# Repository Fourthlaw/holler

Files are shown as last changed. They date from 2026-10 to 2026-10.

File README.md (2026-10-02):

# Holler

**Whole-home audio and intercom.** Synchronized music in every room and a push-to-talk intercom, built yourself. A Raspberry Pi runs the house. Small ESP32-S3 speakers in each room play the music and carry the pages. Paired iPhone and Android apps page the house from anywhere. The music comes from Plex or from a plain network share.

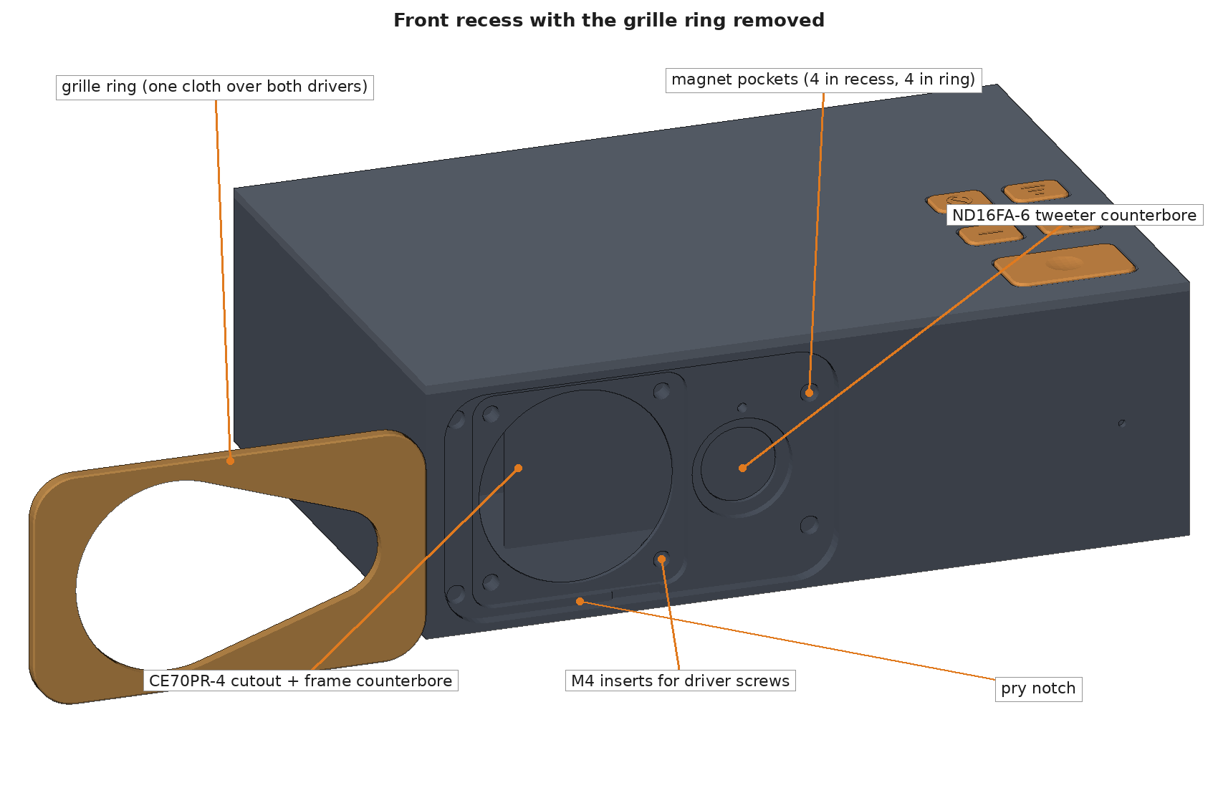
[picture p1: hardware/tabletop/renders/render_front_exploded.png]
Tabletop endpoint with the magnetic grille removed


> **Status: design stage.** The system design and first printable designs for two speakers (tabletop and in-wall) are here. No firmware, controller software, or phone app has been written yet, and nothing has been printed or tested. Expect things to change.

The name comes from what it replaces, hollering across the house, and from "hoot-n-holler," the old term for an always-open intercom line.

## What it does

- **Music in every room, in sync.** One stream plays through the whole house with no echo between rooms.
- **Your library, two ways.** Use Plex and pick music in Plexamp (needs a Plex Pass), or point it at a network share and pick music from a web page or any MPD app, with no account at all.
- **Background mode.** Any room can switch to a soft "music from the other room" sound for dinner or conversation, while the rest of the house plays normally. One button on the speaker turns it on or off, and the server can schedule it.
- **Push-to-talk intercom.** Hold TALK in any room to page every other room. Music ducks while someone is talking, then comes back.
- **Priority page.** Double-press TALK to get through to rooms that are turned down.
- **Phone apps.** A paired iPhone or Android phone can page the house and hear house pages from anywhere, with no VPN.
- **Two ways to reach home.** By default the phone and the house meet through a small server you host, and no port is opened at home. A simpler direct option forwards two ports instead, with no server to run, at the cost of exposing a service at home.
- **Works through a power blip.** The tabletop speaker has a battery that keeps it online for hours.

## Privacy comes first

A microphone in every room has to be provably off.

- A room's mic has power only while someone in that room is holding TALK **and** that room's mic mute is off.
- Both conditions are wired in hardware. The firmware can see the state but has no wire that can change it, so a software bug or a compromised device cannot turn a mic on.
- A soft red glow behind the speaker cloth shows mic mute. It is driven by the same hardware latch, so it cannot be faked.
- No bright lights. Every indicator is indirect and dim enough for a bedroom at night.
- Nothing remote can listen to a room. The phone app can talk to the house and hear a page that someone in the house chose to send. That is all.
- Whatever sits between a phone and the house, a hosted server or the open internet, only ever carries encrypted audio it cannot decrypt.

## How it fits together

```mermaid
flowchart LR
    Library[Music library<br/>Plex server or network share] --> Player
    subgraph Pi[Raspberry Pi 5 controller]
        Player[Plexamp or MPD] --> Snap[Snapserver<br/>synced music]
        Intercom[Intercom server]
        Gateway[Remote gateway]
        Web[Web app and MQTT]
    end
    Snap --> Rooms
    Intercom <--> Rooms
    subgraph Rooms[Room endpoints, ESP32-S3]
        Table[Tabletop speaker]
        Wall[In-wall speaker, optional]
    end
    Gateway <-->|outbound only| Cloud[Rendezvous server<br/>cloud, untrusted]
    Phone[iPhone and Android<br/>PTT apps] <--> Cloud
    Phone -.->|direct mode, optional| Gateway
```

| Part | What it is |
|---|---|
| Controller | Raspberry Pi 5 running Snapcast for music, the intercom server, MQTT, and a local web app |
| Music library | Plex mode: Plex Media Server with a headless Plexamp player on the Pi, controlled from Plexamp. Share mode: a network share played by MPD on the Pi, controlled from a web page or any MPD app. Either one feeds Snapcast |
| Tabletop endpoint | ESP32-S3, 2.5 in. woofer and dome tweeter in a folded transmission line, USB-C power, battery backup. This is the reference build |
| In-wall endpoint (optional) | ESP32-S3, 2 in. speaker, and mic behind a printed plate in a double-gang box. One Ethernet cable brings power (PoE) and data; there is no other power option. Same audio electronics and firmware. Parts are modeled, not yet printed |
| Phone apps | Push-to-talk apps for iPhone (WebRTC and Apple's PushToTalk framework) and Android (WebRTC and a foreground service) |
| Rendezvous server (default) | A small hosted server that helps the phone and the house find each other and punch through to each other. It relays encrypted audio and never holds the keys |
| Direct mode (optional) | No hosted server. The router forwards two ports to the Pi's remote gateway. Simpler and free, but it exposes a service at home to the internet |

The full design, including the mic privacy circuit, the audio processing chain, and the remote intercom trust model, is in **[docs/design.md](docs/design.md)**.

## The tabletop speaker

| | |
|---|---|
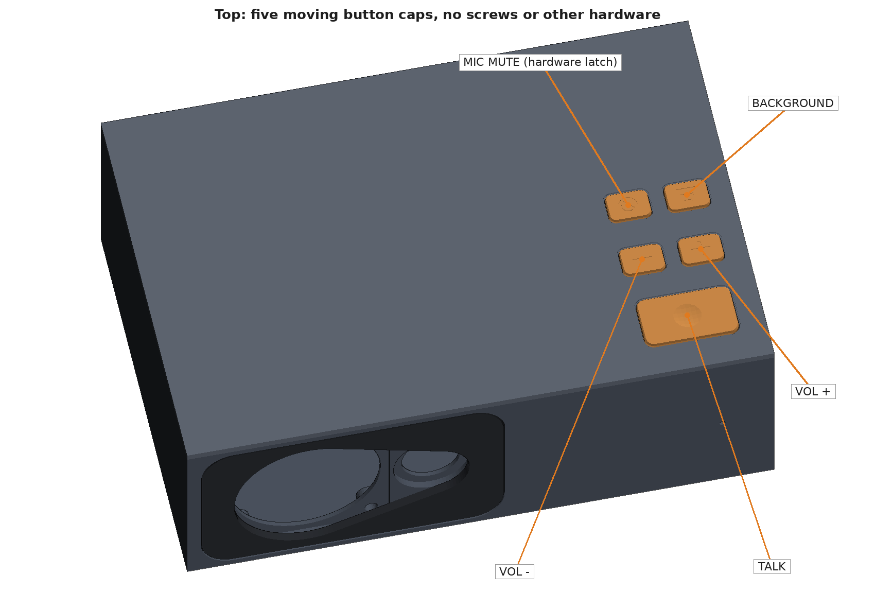
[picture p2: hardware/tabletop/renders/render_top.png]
Top view with the five buttons
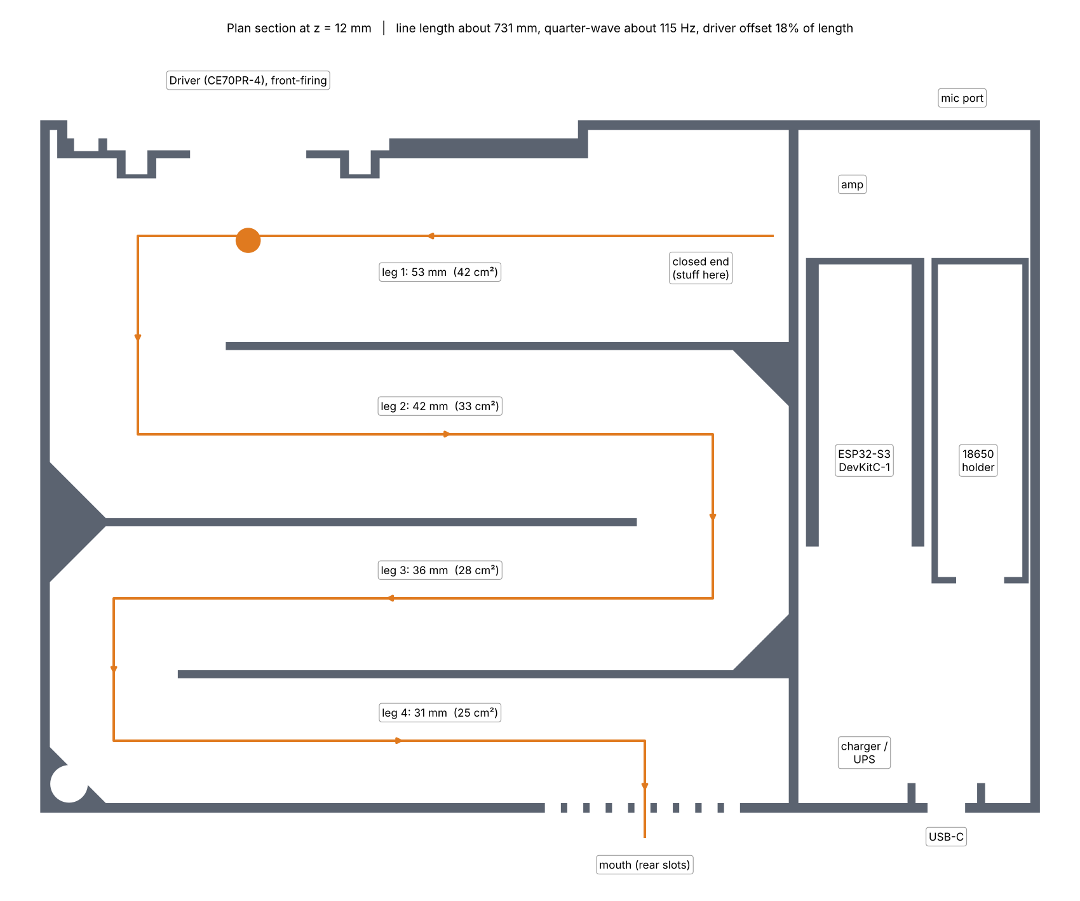
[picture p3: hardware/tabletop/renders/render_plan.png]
Transmission line layout
|  |  |

- 250 x 173 x 84 mm. Prints on a Bambu Lab A1 (256 mm bed) in PETG with no supports.
- Dayton Audio CE70PR-4 2.5 in. woofer and ND16FA-6 tweeter, one amp channel each, with the crossover and EQ done in software.
- A folded transmission line about 730 mm long behind the woofer, tuned to about 115 Hz.
- Five real buttons on top: TALK, volume down, volume up, mic mute, and background mode. No screws on top; they come in from the bottom.
- A cloth grille on a printed ring that snaps on with magnets.
- The status glow sits behind the cloth. Nothing lit points at the room.
- More detail, the hardware list, and assembly steps are in [`hardware/tabletop/`](hardware/tabletop/).

### Print it or change it

| File | Print orientation |
|---|---|
| `hardware/tabletop/base.stl` | Floor on the bed |
| `hardware/tabletop/lid.stl` | Top face on the bed |
| `hardware/tabletop/button_caps.stl` | Cap tops on the bed |
| `hardware/tabletop/grille_ring.stl` | Front face on the bed |

Every dimension is a named parameter at the top of `tabletop_endpoint.py`. Change one and regenerate:

```
cd hardware/tabletop
pip install manifold3d trimesh numpy pillow matplotlib
python3 tabletop_endpoint.py     # writes the STLs
python3 render_views.py          # writes preview images to renders/
python3 render_plan.py           # writes the line layout to renders/
```

Dimensions marked `VERIFY` in the script are estimates. Check them against the parts in hand before printing.

## The in-wall option

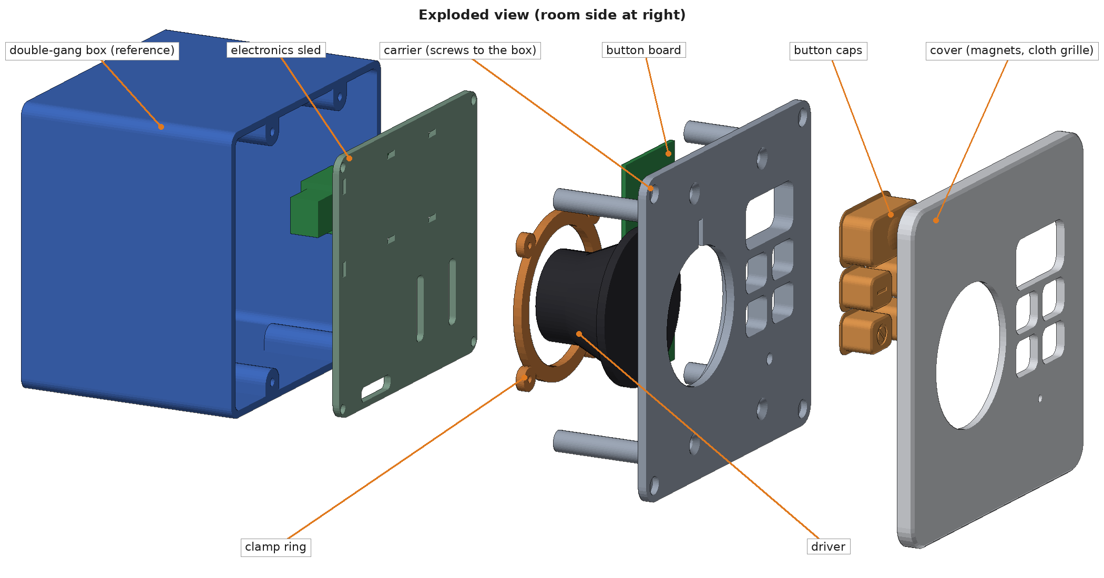
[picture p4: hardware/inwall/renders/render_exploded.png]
In-wall endpoint, exploded


For new construction or a remodel, the same electronics fit a standard double-gang electrical box.

- One Ethernet cable from a PoE switch brings power and data. That is the only power option, so no line voltage comes near the box.
- Everything mounts on one printed carrier that screws to the box's standard device holes. A cover snaps on with magnets, so no screws show.
- One 2 in. driver, the same five buttons, and the same hardware mic gating.
- Parts, hardware list, and assembly steps are in [`hardware/inwall/`](hardware/inwall/).

## What is in this repo

| Folder | What it holds | Status |
|---|---|---|
| [`docs/`](docs/) | System design | Current |
| [`hardware/tabletop/`](hardware/tabletop/) | Tabletop enclosure: generator, STLs, renders | First design, not yet printed |
| [`hardware/inwall/`](hardware/inwall/) | In-wall endpoint (optional): generator, STLs, renders | First design, not yet printed |
| [`firmware/endpoint/`](firmware/endpoint/) | ESP32-S3 firmware for both endpoint types | Not started |
| [`controller/`](controller/) | Pi 5 services | Not started |
| [`remote/`](remote/) | Remote intercom: Pi gateway, rendezvous server, iPhone and Android apps | Not started |

## Roadmap

- [x] System design
- [x] Tabletop enclosure, first design
- [ ] Print and fit-check the tabletop enclosure
- [ ] Mic privacy board (latch, load switches, buffer)
- [ ] Endpoint firmware: music playback, then intercom, then audio tuning and background mode
- [ ] Controller: Snapcast, Plexamp or MPD, intercom server, web app
- [x] In-wall endpoint parts, first design (optional)
- [ ] Remote intercom on the local network (web page)
- [ ] Rendezvous server and iPhone app
- [ ] Android app
- [ ] Direct mode (port forward) as an option

## Feedback

Ideas, corrections, and questions are welcome. Open an [issue](../../issues). Review of the mic privacy circuit and the remote intercom trust model is especially useful.

## License

No license has been chosen yet. Until one is added, the contents are published for reading and all rights are reserved.

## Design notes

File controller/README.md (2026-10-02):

# Holler controller (Raspberry Pi 5)

Not started. Services planned (see docs/design.md, section 2):

- Music source, one of two modes:
  - Plex mode: Plex Media Server for the library (here or on another machine) and Plexamp headless as the house player, feeding Snapserver through an ALSA loopback
  - Share mode: MPD playing from a network share into a Snapserver pipe, with a music page in the web app
- Snapserver for synchronized music
- Intercom server: PTT arbitration, Opus relay, priority pages
- Mosquitto MQTT broker with per-device credentials
- Web app (Flask or FastAPI): music, volumes, schedules, phone pairing
- Scheduler for alarms and announcements

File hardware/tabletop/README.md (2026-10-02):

# Holler tabletop endpoint

The reference build: a desktop speaker with USB-C power and a battery that carries it through outages. This is a first design. It has been modeled and checked for fit, but not yet printed.

See docs/design.md, section 3.4, for the full design.

Front, with the grille ring removed

| | |
|---|---|
| Top | Transmission line layout |

## What it is

- 250 x 173 x 84 mm, printed in PETG on a Bambu Lab A1 with no supports
- Dayton Audio CE70PR-4 2.5 in. woofer and ND16FA-6 tweeter, front-mounted in a recess, each on its own MAX98357A amp, with the crossover in software
- A folded transmission line about 730 mm long behind the woofer, tuned to about 115 Hz
- ESP32-S3-DevKitC-1 on Wi-Fi, INMP441 mic, USB-C power, and an 18650 cell for backup
- Five moving button caps on top: TALK, VOL -, VOL +, MIC MUTE, BACKGROUND
- A cloth grille on a printed ring held by magnets
- Lid screws come up through the bottom, so nothing shows on top but the buttons
- The status glow is indirect: an LED under the grille ring shines sideways behind the cloth

## Parts

| File | What it is | Print orientation |
|---|---|---|
| `base.stl` | Case, transmission line, electronics bay | Floor on the bed |
| `lid.stl` | Top, button guides, and the pillars the bottom screws thread into | Top face on the bed |
| `button_caps.stl` | All five caps on one plate | Cap tops on the bed |
| `grille_ring.stl` | Magnetic frame for the speaker cloth | Front face on the bed |

The base uses roughly 450 to 500 g of PETG and nearly fills the A1 bed. Print one cap and a small test piece of the lid first to check the cap fit.

## Hardware

| Item | Qty |
|---|---|
| Dayton Audio CE70PR-4 woofer and ND16FA-6 tweeter | 1 each |
| MAX98357A I2S amp breakout | 2 |
| 10 to 22 uF film capacitor (in series with the tweeter) | 1 |
| ESP32-S3-DevKitC-1, INMP441 mic module | 1 each |
| 18650 cell and holder, power-path charger, 5 V boost, USB-C breakout | 1 each |
| 3 mm bicolor LED (red/green) | 1 |
| 6x6 mm tact switch | 5 |
| M3 heat-set insert and M3 x 8 socket head screw (lid) | 6 |
| M4 heat-set insert and M4 x 10 screw (woofer) | 4 |
| M2 x 5 self-tapping screw (button board) | 4 |
| 6 x 3 mm disc magnet | 8 |
| 12 mm self-adhesive feet | 4 |
| Speaker cloth, foam gasket tape, polyfill, zip ties | |

Assembly steps are in docs/design.md, section 3.4.5.

## Change it

Every dimension is a named parameter at the top of `tabletop_endpoint.py`:

```
pip install manifold3d trimesh numpy pillow matplotlib
python3 tabletop_endpoint.py     # writes the STLs
python3 render_views.py          # writes preview images to renders/
python3 render_plan.py           # writes the line layout to renders/
```

Dimensions marked `VERIFY` are estimates. Check them against the parts in hand before printing: the woofer frame and basket, the tweeter faceplate, the mic board, the 18650 holder, the tact switch height, and the USB-C breakout.

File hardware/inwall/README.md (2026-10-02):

# Holler in-wall endpoint (optional)

An option for people who want speakers in the walls. It is not part of the reference build. The parts here are a first design: modeled and checked against each other and a reference box, but not yet printed or fitted to a real box.

The electronics, mic privacy circuit, buttons, and firmware are the same as the tabletop endpoint. See docs/design.md, section 3.1.

Exploded view

| | |
|---|---|
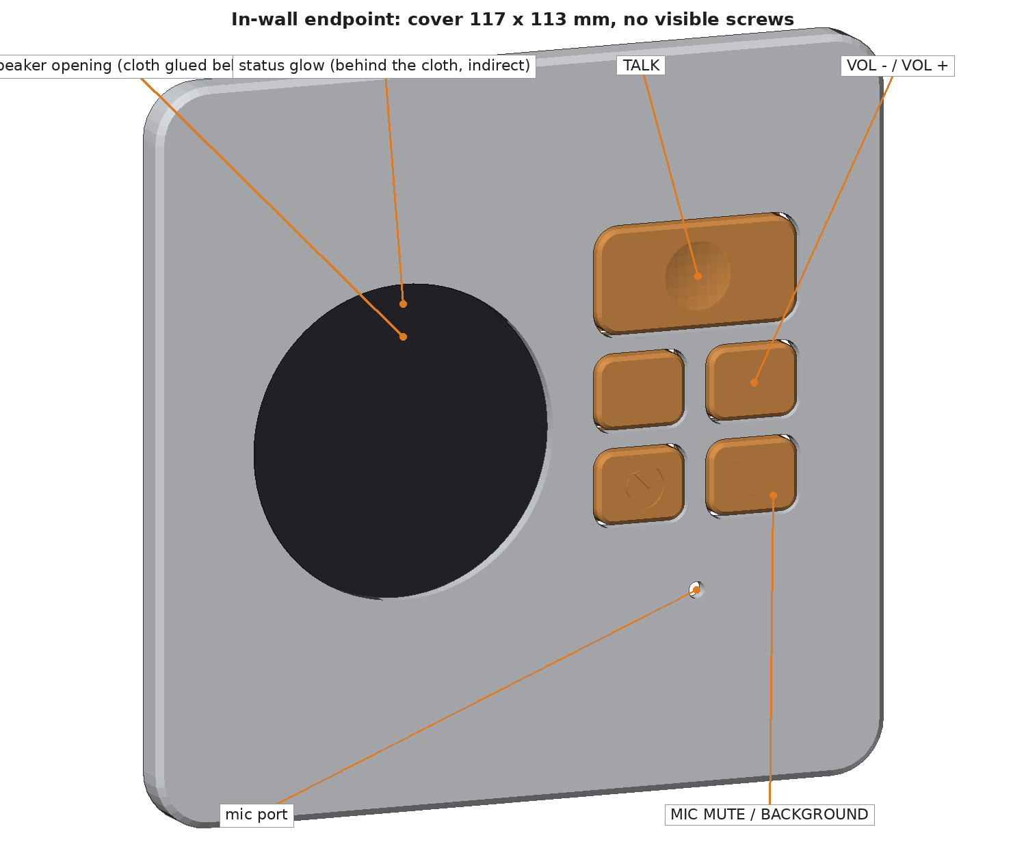
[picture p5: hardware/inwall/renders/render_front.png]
Front
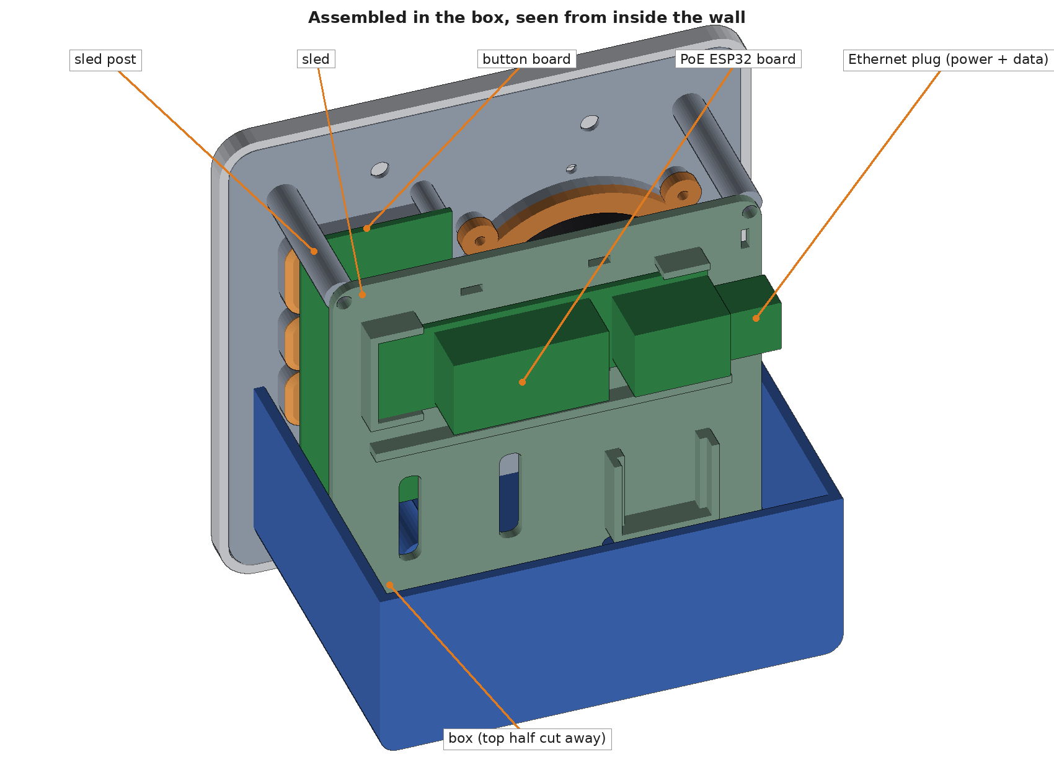
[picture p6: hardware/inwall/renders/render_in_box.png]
Assembled in the box
|  |  |

## What it is

- A standard double-gang new-work box (Carlon B232A class) used as a sealed speaker enclosure
- One 2 in. full-range driver (Dayton Audio CE52N-4) and one MAX98357A amp
- An ESP32-S3 board with Ethernet and a PoE module (Waveshare ESP32-S3-ETH, PoE version). One Ethernet cable from a PoE switch powers and connects it. There is no other power option
- INMP441 mic behind a gasketed port
- Five moving button caps: TALK, VOL -, VOL +, MIC MUTE, BACKGROUND
- A cover held on by magnets, so no screws show
- No light on the plate: the status glow is indirect, behind the speaker cloth

## Parts

| File | What it is | Print orientation |
|---|---|---|
| `carrier.stl` | Plate that screws to the box's four device holes and carries everything | Front face on the bed |
| `sled.stl` | Electronics plate that screws to the carrier's four posts | Flat, trays up |
| `cover.stl` | Wall plate, 117 x 113 mm | Front face on the bed |
| `button_caps.stl` | All five caps on one plate | Cap tops on the bed |
| `driver_ring.stl` | Clamp ring for the driver | Flat |
| `box_reference.stl` | The electrical box, for fit checks. **Do not print** | |

PETG, no supports. The carrier's sled posts are 35 mm tall and 7 mm across; slow down for them if they wobble.

## Hardware

| Item | Qty |
|---|---|
| 6-32 flat-head device screw (usually supplied with the box) | 4 |
| M3 heat-set insert and M3 x 6 screw (sled to posts) | 4 |
| M2 heat-set insert and M2 x 6 screw (driver ring) | 4 |
| M2 x 5 self-tapping screw (button board) | 4 |
| 6 x 2 mm disc magnet (4 in the carrier, 4 in the cover) | 8 |
| 6x6 mm tact switch | 5 |
| Speaker cloth, foam gasket tape | |

## Assembly

1. Press the inserts into the sled posts and the driver clamp bosses. Glue the magnets into the carrier and the cover with matching polarity.
2. Seat the driver in the carrier and clamp it with the ring.
3. Drop the five caps into their collars from the back, then screw the button board onto its standoffs. The board holds the caps in.
4. Seat the mic in its pocket, port toward the room. Lay the status LED in the groove at the top of the speaker opening, facing the centre, with its wires through the hole.
5. Fit the PoE ESP32 board and the amp to the sled, wire everything, and screw the sled to the posts. Plug in the Ethernet cable and tie it to the sled.
6. Screw the carrier to the box with the four device screws, with foam tape between the carrier and the wall.
7. Glue cloth behind the cover's speaker opening, put a foam ring around the mic port, and set the cover on.

## Change it

Every dimension is a named parameter at the top of `inwall_endpoint.py`:

```
pip install manifold3d trimesh numpy pillow
python3 inwall_endpoint.py     # writes the STLs and prints fit checks
python3 render_views.py        # writes preview images to renders/
```

The script reports the overlap between every pair of parts, the dummy components, and the box. All should be zero.

Dimensions marked `VERIFY` are estimates. The ones that matter most: the box's interior size and how far its screw bosses reach in, the driver's flange and basket, the mic board's diameter and port position, the height of the PoE board's RJ45 jack and PoE module, and how far the Ethernet plug sticks out. For a different PoE board, change `ESP_BOARD`.

## Before installing in a wall

- Power is PoE only. Never bring line voltage into this box.
- Run the Ethernet cable from a PoE switch or injector. Do not connect USB while PoE is plugged in.
- Use in-wall-rated cable, and follow local electrical code.

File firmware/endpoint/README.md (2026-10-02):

# Holler endpoint firmware (ESP32-S3)

Not started. One firmware for both endpoint types, built with ESP-IDF, with two build targets:

| Target | Board | Network | Audio out |
|---|---|---|---|
| Tabletop | ESP32-S3-DevKitC-1 | Wi-Fi | Two amp channels, software crossover, battery reporting |
| In-wall | ESP32-S3 with Ethernet and PoE (Waveshare ESP32-S3-ETH) | Wired Ethernet (W5500) | One amp channel |

Planned pieces (see docs/design.md, sections 3.1.2 and 3.4.3):

- Snapcast client for music (based on the community ESP32 snapclient)
- Intercom: Opus over UDP/RTP multicast, PTT capture, local ducking, priority pages
- Audio processing: EQ, crossover, bass boost, limiter, and background mode (esp-dsp)
- MQTT over TLS for control and telemetry
- Five buttons: TALK and its double-press gesture, volume, and the BACKGROUND toggle. MIC MUTE is read only
- Status glow: the firmware drives green only, and only in answer to a button press. Red is driven by hardware
- Signed OTA updates

The firmware can read the mic mute and PTT state but has no way to change them. Keep it that way.

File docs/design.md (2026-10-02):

# Holler: System Design

Whole-home synchronized music and push-to-talk intercom.

## 1. Goals

- Whole-home synchronized music playback, same program in all rooms.
- Intercom: any room can press PTT and page all rooms. No per-room routing.
- Music ducking: music level drops (or mutes) while intercom audio plays, then restores.
- Low hardware cost and low in-wall complexity for standard rooms.
- Upgradeable: some rooms can use higher-fidelity stereo endpoints.
- All endpoints digitally controllable (volume, mute, overrides) from a central controller.
- Privacy by design: a room microphone is powered only while someone in that room holds PTT and the room's mic mute is off. Both conditions are enforced in hardware. No software path, including compromised firmware, can enable a microphone.
- Media hosting and control, two ways: Plex (library and remote control, needs a Plex Pass) or a plain network share with an open-source player (no accounts, no subscription). A household picks one.
- No bright lights: every indicator on every endpoint is indirect and dim enough for a bedroom at night. No LED points at the room, and nothing blinks or pulses on its own.
- Background mode: any room can switch its music to a soft "playing in the next room" sound without changing what the rest of the house hears.
- Remote intercom: family phones (iPhone and Android) can page the house and hear house pages from anywhere, without a VPN. The default path opens no inbound port at home; a simpler direct path that does is offered as a lower-security option. Remote access covers the intercom only, not the music stream or house controls.

---

## 2. System architecture

### 2.1 Central controller (Raspberry Pi 5)

**Hardware**

- Raspberry Pi 5.
- Wired Ethernet.
- On UPS power, same as the PoE switch (see 3.1.1 Power).

**Roles**

1. **Music distribution**
   - Runs Snapserver for synchronized multi-room audio.
   - Sources: the music library through Plexamp or MPD (2.4), internet radio, TTS, alert tones.
   - Snapcast buffers audio (default about 1 s) to keep rooms in sync. That is fine for music and is the reason intercom uses a separate path.

2. **Intercom server**
   - Low-latency path, separate from Snapcast.
   - Transport: Opus over UDP/RTP multicast on the endpoint VLAN. Target end-to-end latency under 150 ms.
   - Arbitration: first endpoint to press PTT holds the channel. Any other endpoint that presses PTT while the channel is held gets a "busy" LED indication and does not transmit. A priority page does not pre-empt a page already in progress; it waits for the channel like any other.
   - Relays the active talker's audio to all other endpoints. The talking endpoint does not receive its own audio.

3. **Control and orchestration**
   - Web application (Flask or FastAPI):
     - Play/pause, source select, global volume.
     - Per-endpoint volume and mute.
     - Schedules and alarms.
     - Intercom status.
   - Endpoint control over MQTT (Mosquitto broker on the Pi) with per-device credentials.
   - REST/WebSocket API for the web UI and integrations.

4. **Scheduling and alarms**
   - Scheduler for morning alarms, timed announcements, and quiet-hours windows.
   - Alarm events play a stream or sound file through Snapserver and can apply a system volume override (see 3.1.2 volume rules).

### 2.2 Network and security

- Endpoints live on a dedicated IoT VLAN. Only the controller is reachable from that VLAN; endpoints cannot reach the internet.
- MQTT with TLS and a unique username/password (or client cert) per endpoint. Endpoints ignore commands from any other source.
- OTA firmware images are signed (ESP-IDF secure boot / signed app images). Endpoints reject unsigned images.
- No inbound services on endpoints beyond what the audio and control protocols require.
- By default nothing at home accepts inbound connections from the internet. Remote intercom (2.3) runs over an outbound connection from the Pi. The optional direct mode in 2.3 is the one exception, and it forwards only the remote gateway's two ports.

### 2.3 Remote intercom (phone apps)

**Scope:** intercom only. A remote phone can page the house and hear house pages. It cannot join the music stream, change volumes, read room state, or reach any admin or firmware function. Music and house controls stay on the local network and the local web app.

**Two ways to connect**

A household picks one. The apps, the pairing, and the audio encryption are the same in both.

| | Rendezvous mode (default) | Direct mode (lower security) |
|---|---|---|
| How the phone reaches home | Both sides connect out to a small hosted server, which introduces them and hole-punches a path | The phone connects straight to the house through two forwarded ports |
| Inbound ports open at home | None | Two (one TCP, one UDP), forwarded to the remote gateway |
| Hosted server | Yes, a small VPS (about $5 a month) | None |
| What the internet can reach | A disposable server that holds no keys and no house controls | A service running inside the home network |
| Works behind carrier-grade NAT | Yes | No. Needs a public IP address at home (or IPv6 at both ends) |
| Third parties that see connection metadata | Your own server, plus Apple or Google for push | Apple or Google for push |
| Audio encryption and pairing | End to end, same in both | End to end, same in both |

Rendezvous mode is the recommendation. Direct mode exists for people who do not want to run a hosted server and accept the exposure described below.

**Pieces**

| Piece | Runs on | Job |
|---|---|---|
| Remote intercom gateway | Pi 5 | Terminates the phone's WebRTC audio and bridges it to and from the house intercom. In rendezvous mode it holds an outbound connection to the server; in direct mode it listens on the forwarded ports |
| Rendezvous server (rendezvous mode only) | Small cloud VPS | Relays setup messages between the Pi and phones, runs a TURN relay (coturn) for when a direct path fails, and sends push notifications to wake phones |
| Holler app for iPhone | iPhone | Push-to-talk app built on Apple's PushToTalk framework (iOS 16 and later) and WebRTC |
| Holler app for Android | Android phone | Push-to-talk app built on WebRTC, a foreground service, and Firebase Cloud Messaging for wake-up |

**Trust model (both modes): authenticate end to end, trust nothing in between**

WebRTC encryption is only as good as the setup messages that carry each side's DTLS fingerprint. Anything that can alter those messages could sit in the middle. So setup is authenticated end to end, independent of the path:

- **Pairing on the home network:** each phone is paired once, in person, on the LAN. The Pi's local web UI shows a QR code; the app scans it. The phone and the Pi exchange Ed25519 public keys. The Pi records the phone's key, name, and permissions. The QR code also carries how to reach the house: the rendezvous server address, or the home address and ports for direct mode.
- **Signed setup messages:** every offer, answer, and session message is signed by its sender's device key and carries a nonce and timestamp (replay protection).
- **Fingerprint binding:** the DTLS fingerprint is inside the signed message. Each side rejects a connection whose actual fingerprint does not match a signed message from a paired device.
- **Result:** whatever sits between the phone and the Pi sees who is talking to whom and when, plus encrypted packets. It cannot listen, inject audio, or impersonate a phone or the house.

**Rendezvous mode**

- The Pi keeps one outbound secure WebSocket (TLS on 443) open to the rendezvous server. That is the only connection home makes to the internet for this feature. No port forwarding, no inbound rules, no VPN.
- The phone also connects to the rendezvous server over a secure WebSocket, only when it needs to: when the user presses TALK, or when a push says a page is starting.
- Audio runs over WebRTC between the phone and the Pi: Opus, mono, about 24 to 32 kbps, encrypted end to end with DTLS-SRTP.
- Both sides first try a direct path (ICE with STUN, which punches through most home NATs). When that fails, common on cellular networks, the audio relays through TURN on the rendezvous server. Either way the server never holds the media keys.
- The server is treated as untrusted. If it is taken over, the attacker gets an address book and encrypted packets.

Rendezvous server hardening:

- Open ports: 443/tcp (WebSocket and TLS), 3478 udp/tcp (STUN/TURN), and a narrow UDP relay port range for TURN. Nothing else.
- TURN credentials are short-lived and issued per session (the TURN REST credential scheme), so a leaked credential expires in minutes.
- Rate limits on connections, setup messages, and push requests per device.
- The Pi authenticates to the server with its own device key; the server accepts only the paired Pi and paired phones.
- No house control endpoints exist on the server, so there is nothing there to abuse even if it is taken over.
- Minimal logging (device IDs and timestamps, no audio), automatic security updates, and a rebuild-from-script setup so the box can be replaced quickly.

**Direct mode**

- The home router forwards two ports to the remote gateway: one TCP port for setup messages (TLS) and one fixed UDP port for audio. Nothing else on the Pi or the LAN is forwarded.
- The phone finds the house by a dynamic DNS name saved at pairing. It pins the Pi's key from pairing, so no public certificate authority is involved and a look-alike server cannot stand in.
- No hosted server and no monthly cost. To wake phones for house pages, the Pi sends pushes to Apple and Google itself over outbound connections, which means the push credentials live on the Pi.
- Audio uses the same WebRTC, Opus, and DTLS-SRTP as rendezvous mode.

Why it is the lower-security option:

- A service inside the home network is reachable by anyone on the internet. Any flaw in the gateway, or in the TLS and WebRTC libraries under it, can be probed by anyone who finds the ports. In rendezvous mode the same gateway is never directly reachable, and the exposed machine is a disposable server that holds nothing.
- The dynamic DNS name ties the service to the home's address.
- The encryption and pairing are not weaker. What changes is how much is exposed if there is a bug.

Hardening for direct mode:

- The gateway drops any connection whose first message is not signed by a paired device, before doing any other work, and answers nothing. To a scanner the port looks dead.
- Run the gateway as its own unprivileged, sandboxed service. Better, run it on a separate small device in its own VLAN, so a compromise does not land on the controller.
- A local firewall lets the gateway talk only to the intercom server's local port.
- Rate limits and temporary bans on addresses that send bad messages. Non-default port numbers.
- Automatic security updates for the gateway and its libraries.
- Not possible behind carrier-grade NAT, which some ISPs use. Rendezvous mode works there.

**Paging from the phone**

1. User presses TALK in the app. The app connects (to the rendezvous server, or straight to the gateway in direct mode) and sends a signed offer to the Pi.
2. The Pi verifies the signature and the phone's permissions, then requests the house intercom channel exactly as a room endpoint would. If another room holds the channel, the app shows busy.
3. Audio flows phone to Pi over WebRTC; the Pi relays it onto the house intercom multicast. Rooms duck music and play it like any other page.
4. Priority page from a phone works only if that phone's permissions allow it.

**Hearing house pages on the phone**

1. A room starts a page. The Pi begins buffering the audio and requests a push to each subscribed phone (through the rendezvous server, or directly to Apple and Google in direct mode).
2. The push wakes the app (see the two apps below).
3. The app connects and the Pi plays the buffered page from the start, then live. Expect about 1 to 2 seconds of added delay on the phone for the first page after the app wakes.
4. Each phone can turn its page subscription off (for example at night or at work).

**iPhone app**

- Swift, the standard WebRTC framework, and Apple's PushToTalk framework.
- A PushToTalk push wakes the app and shows the system talk UI, even when the phone is locked.
- Needs a paid Apple developer account ($99 a year), which also allows installing on family phones through TestFlight.

**Android app**

- Kotlin and Google's WebRTC library. Same pairing, signing, and permissions as the iPhone app.
- Hearing pages: a high-priority Firebase Cloud Messaging (FCM) message wakes the app, which starts a foreground service to connect and play the page. Android allows a foreground service to start from the background for a high-priority FCM message. The app checks that the message was not downgraded to normal priority before it starts the service.
- Talking: on Android 14 and later, a foreground service that uses the microphone has to start while the app is visible. So talking means opening the app, or tapping the page notification, and holding TALK. There is no lock-screen talk button like the one Apple's framework provides.
- Distribution: the APK can be installed directly on family phones at no cost. A Play Store listing is optional (one-time $25 developer fee).
- FCM needs Google Play services. Phones without it would need a persistent connection instead; that is left as a later option.
- Android background rules change between versions. Verify them against the current Android documentation when the app is built.

**Permissions (set per phone, at the Pi)**

| Permission | Default |
|---|---|
| Page the house | on |
| Priority page | off |
| Receive house pages | on |
| Music, volumes, room state, admin | not available remotely, for any phone |

Revoking a phone at the Pi takes effect immediately. The rendezvous server only ever holds public keys and push tokens.

**Mic privacy is unchanged.** Nothing remote can open a room microphone, in either mode. A house page reaches a phone only because someone in a room is holding TALK, and the room mics stay behind the hardware PTT and mute latch circuit (3.1.1).

**Build notes**

- Pi side: Pion (Go) or aiortc (Python) for WebRTC.
- Phase 1, on the LAN only: a small web page served by the Pi that does WebRTC paging from a phone browser. It proves the gateway and signing scheme with no app and no hosted server.
- Phase 2: one remote path (rendezvous first) and one native app. The second app and direct mode follow.
- The two apps share the protocol, not code. A shared-code framework would not remove the native push-to-talk and background pieces, which are most of the work.

### 2.4 Music library and control

Snapcast delivers whatever is playing to the rooms. What feeds Snapcast, and what people use to pick music, is one of two modes. A household chooses one at setup.

| | Plex mode | Share mode |
|---|---|---|
| Library lives on | Plex Media Server | Any network share (SMB or NFS) or a local disk |
| Player on the Pi | Plexamp headless | MPD (Music Player Daemon) |
| Pick music with | Plexamp on a phone or desktop | A web page served by the Pi, or any MPD client app |
| Accounts and cost | Plex account with a Plex Pass | None |
| Needs internet | Yes, for Plex sign-in | No |
| Playlists, queue, search | Yes | Yes |
| Smart mixes and artist radio | Yes | No |

Both modes end the same way: the player's audio goes into Snapserver, and every room plays it in sync. Play, pause, and skip take about a second to be heard because of the Snapcast sync buffer. Volume per room is set at each endpoint or in the local web app, in either mode.

**Plex mode**

```
Plex Media Server (library) -> Plexamp headless on the Pi 5 (a Plex player named "House")
        -> ALSA loopback device -> Snapserver (alsa source) -> every endpoint, in sync
```

- Plexamp headless runs on the Pi 5 and appears in Plex as a player. Choosing it as the player in Plexamp on a phone plays that music through every room.
- Plexamp's audio output is pointed at an ALSA loopback device. Snapserver reads the other side of the loopback as a stream source.
- Headless Plexamp requires a Plex Pass on the account that owns the player. Other members of the Plex Home can play to it without their own.
- Install Plexamp directly on the Pi, not in Docker. Others report playback errors with the Docker route.
- Plex signs in through plex.tv, so the Pi needs outbound internet for this piece. The room endpoints still do not.
- Plex Media Server can run on the Pi 5 or on another machine or NAS on the LAN. For a music library the Pi 5 is enough. If the same server also transcodes video for TVs, put it on a stronger machine.

**Share mode**

```
Network share or local disk (music files) -> MPD on the Pi 5 -> FIFO pipe -> Snapserver (pipe source)
        -> every endpoint, in sync
```

- The Pi mounts the share read-only. MPD indexes it and plays from it. MPD into a Snapserver pipe is the standard Snapcast setup.
- Control: a music page in the Pi's web app (browse, search, queue, playlists, play, pause, skip), built on MPD's control protocol. The open-source myMPD web client can stand in until that page exists. Any MPD client app on a phone also works.
- The share can be the same folder a Plex server uses. A household without a Plex Pass can keep Plex for TVs and still drive the house music from the share.
- No account, no subscription, and nothing leaves the LAN.

**Switching and coexisting**

- Snapserver can hold both sources at once, so both players can be installed and the active one chosen in the web app. The setup default is one mode, to keep things simple.
- Internet radio, announcements, and alarms are separate Snapserver sources in both modes.

**Video** is outside this system. Plex serves TVs and phones directly as it normally does.

**To be tested:** the Plexamp to ALSA loopback to Snapserver chain on the Pi 5 (sample rate handling, gapless playback), and MPD library scan time on a large share.

---

## 3. Endpoint types

| Type | Section | What it is | Status |
|---|---|---|---|
| Tabletop | 3.4 | Printed desktop speaker, USB-C, battery backup, woofer and tweeter | Reference build. Enclosure designed, not yet printed |
| In-wall | 3.1 | Mono speaker and mic behind a printed plate in a double-gang box. One Ethernet cable carries power (PoE) and data | Optional. Parts modeled, not yet printed |
| HiFi | 3.2, 3.3 | Raspberry Pi feeding stereo speakers or an existing receiver | Optional |

The tabletop endpoint is the one being built first. The in-wall endpoint is kept in the design as an option for anyone who wants speakers in the walls. Both use the same electronics, mic privacy circuit, buttons, and firmware, which are described once in 3.1.1 and 3.1.2 and referred to from the tabletop section.

### 3.1 In-wall endpoint (optional; mono, ESP32-S3)

**Use case:** rooms where a speaker in the wall is wanted instead of a box on a table.

**Status:** an option, not part of the reference build. The electronics and firmware below are shared with the tabletop endpoint and are current. The in-wall mechanical parts are modeled in `hardware/inwall/` (carrier, electronics sled, cover, button caps, driver ring) but have not been printed or fitted to a real box.

**Differences from the tabletop endpoint**

| | In-wall | Tabletop |
|---|---|---|
| Speaker | One 2 in. full-range driver, sealed in the box | 2.5 in. woofer and dome tweeter, transmission line |
| Amp | One MAX98357A | Two MAX98357A, software crossover |
| Power | PoE only, over the Ethernet cable | USB-C with 18650 backup |
| Network | Wired Ethernet only (the same cable) | Wi-Fi |
| MCU board | ESP32-S3 with Ethernet and a PoE module | ESP32-S3-DevKitC-1 |
| Enclosure | Double-gang box, printed plate and bracket | Printed case |
| Install | Low-voltage wiring in the wall | None |

#### 3.1.1 Hardware

**MCU**

- ESP32-S3 with PSRAM. The S3 has two I2S peripherals: I2S0 drives the amplifier, I2S1 reads the microphone.
- In-wall: an ESP32-S3 board with onboard Ethernet and a PoE module. The model is built around the Waveshare ESP32-S3-ETH in its PoE version (72.8 x 21 mm, W5500 Ethernet, 802.3af PoE module, 16 MB flash, 8 MB PSRAM). Its Ethernet chip uses GPIO 9 to 14 internally, which leaves enough pins for the amp, mic, buttons, and LED.
- Tabletop: ESP32-S3-DevKitC-1 on Wi-Fi (3.4.3).

**Amplifier**

- Preferred: Adafruit I2S 3W Class D Amplifier Breakout (MAX98357A).
  - I2S input with built-in DAC and Class-D amp.
  - Up to about 3.2 W into 4 ohms at 5 V.
  - About 19.4 x 17.8 x 3 mm.
  - SD pin can select left, right, or (L+R)/2 in hardware, so downmix can happen in the chip.
  - GAIN pin sets fixed gain (default 9 dB). Set per build after listening tests.
- Alternates (functionally equivalent): SparkFun I2S Audio Breakout (MAX98357A), DFRobot DFR0954 (MAX98357A).

**Speaker (2 in. class, 4 ohm)**

Sensitivity matters more than power handling here, since the amp only delivers about 3 W.

| Driver | Size | Impedance | RMS | Sensitivity | Response | Notes |
|---|---|---|---|---|---|---|
| Dayton Audio CE52N-4 | 2 in. | 4 ohm | 5 W | 85 dB | 120 Hz - 20 kHz | **Preferred.** Good balance of output and low end. |
| Dayton Audio CE53N-4 | 2 in. | 4 ohm | 10 W | 87 dB | 200 Hz - 20 kHz | Louder alternate for large rooms; less bass. |
| Dayton Audio CE48-4 | 2 in. | 4 ohm | 5 W | 79 dB | 120 Hz - 20 kHz | Budget option. About 6 dB quieter than CE52N-4 at the same power. |
| Dayton Audio CE58N-10 | 2 in. | 10 ohm | 15 W | - | - | Not recommended. At 10 ohms the amp delivers well under half its 4 ohm output. |

Confirm depth on the spec sheet before finalizing the bracket.

**Speaker sizing limits (double-gang box)**

- Diameter: 2 to 2.5 in. recommended, about 3 in. maximum.
- Depth: 1 to 1.5 in. recommended, about 2 in. maximum.

**Microphone**

- Preferred: INMP441 I2S MEMS microphone module (ElectroPeak, about $1.75).
  - Omnidirectional, bottom port, digital I2S output, no external preamp or ADC.
  - Outputs 24-bit data in a 32-bit I2S slot. Firmware must shift accordingly.
- Alternates: generic INMP441 modules (same pinout), ICS-43434 modules.

**Mic mounting and isolation**

- The double-gang box acts as the speaker's enclosure, so the mic must be sealed from the inside of the box.
- Mount the module so its port lines up with a 2 to 3 mm hole in the plate. Seal around the port with a foam or silicone gasket so the mic hears only the room.
- Place the mic as far from the speaker as the plate allows.
- Secure the breakout mechanically and strain-relieve the wires.

**Mic privacy circuit (all endpoints with a microphone)**

The microphone is powered only when both of these are true, and each is decided by hardware:

1. PTT is physically held.
2. The mic mute latch is off.

Circuit:

- **Two switches in series on the mic supply.** INMP441 VDD feeds through two load switches (or P-channel MOSFETs) in series. The first is driven directly by the PTT switch contact. The second is driven directly by the mute latch. Either one open means no power to the mic.
- **Mute latch.** The MIC MUTE button (momentary tact switch) goes through an RC debounce and a Schmitt trigger into a D flip-flop (74LVC1G74 class) wired to toggle (/Q fed back to D). Each press flips mute on or off.
- **Power-up state is muted.** An RC on the flip-flop's preset input forces mute on at power-up. After a full power loss, the mic stays off until someone presses MIC MUTE.
- **No back-powering through the data lines.** A powered-down mic can be partly powered through its I2S pins by the ESP32's clocks. SCK, WS, and SD pass through a small logic buffer with Ioff (74LVC class) that is itself powered from the switched mic rail. When the rail is off, the buffer is high-impedance and the mic is fully dead. SD has a pull-down on the ESP32 side.
- **Hardware glow.** The red element of the status light (indirect; see Status light below) is driven directly from the mute latch output through a resistor. Red means the mic is disconnected, and firmware cannot fake it or turn it off.
- **Firmware can read, not write.** The ESP32 reads the PTT line and the mute state on input-only GPIOs through series resistors. No GPIO connects to the latch clock, D, preset, or clear inputs, or to either load switch enable. Verify this with a continuity check on every board before it goes into an enclosure.
- After the mic rail turns on, allow for the INMP441 startup time (tens of ms) before treating samples as valid.

**Controls (moving button caps over tact switches)**

- Five PCB-mounted 6x6 mm tactile switches: `VOL_DOWN`, `PTT`, `VOL_UP`, `MIC_MUTE`, `BACKGROUND`.
- `VOL_DOWN`, `VOL_UP`, and `BACKGROUND` are SPST-NO to ground on GPIOs with internal pull-ups. `PTT` and `MIC_MUTE` drive the mic privacy circuit directly; the ESP32 only reads them.
- `BACKGROUND` sits beside `MIC_MUTE` but is an ordinary software button. It shares no circuitry with the mute latch.

Plate design:

- Each button is a separate printed cap that moves in an opening in the plate. Nothing flexes; the plate stays rigid.
- The cap slides in a short guide collar on the back of the plate (0.3 mm clearance per side), is kept from falling out by a flange under the collar, and has a stem that rests on its tact switch. The switch provides the return spring and the click.
- Caps are loaded from behind before the switch board goes on, so they are captive and there are no visible fasteners.
- The first plan for the in-wall plate was hidden press zones: thinned areas of the plate that flex onto the switches, with nothing visible on the surface. Moving caps replaced them for a better feel and longer life. A flex-zone cover is still possible on the same carrier, since the switches and board would not change.
- Layout: the speaker fills the left gang. The right gang holds the buttons in three rows, top to bottom: TALK, then VOL - and VOL +, then MIC MUTE and BACKGROUND, with the mic port below. The status light is behind the speaker cloth, not on the plate.
- Touch marks engraved in the cap tops: a dish on PTT, minus and plus on volume, a slashed ring on MIC MUTE, three fading bars on BACKGROUND.
- Print plate and caps in PETG. Caps print top-down so the touch surface is the smooth bed side.

The tabletop endpoint (3.4) uses the same cap design at a larger size; its generator is the reference implementation.

**Status light (indirect, on every endpoint)**

Rule for all endpoints: no LED points at the room. The light is a soft glow seen through the speaker grille cloth, dim enough that it does not light a dark bedroom.

- **Placement:** the LED sits behind the grille cloth, hidden from direct view, and shines sideways across the baffle or the driver cone. What the room sees is a faint wash of colour through the cloth, not a point of light. There are no light windows, light pipes, or thin-skin lenses on any face.
  - In-wall: a small LED lies in a groove in the front of the carrier, under the cover, at the top of the speaker opening. It fires across the cone.
  - Tabletop: a 3 mm LED sits in the recess floor above the tweeter, under the solid frame of the grille ring. A hooded channel in the back of the ring lets the light out sideways into the opening.
- **Brightness:** bicolor (red/green), driven at very low current (0.1 to 0.5 mA) through large series resistors. The resistor value is chosen per unit; bedrooms get the dimmest value. Check it in a dark room before closing the unit.
- **Red is hardware-only:** driven by the mic mute latch. A steady, soft glow while the mic is disconnected. Firmware has no control over it. It never blinks or pulses.
- **Green is firmware, and only in answer to a button press:**
  - Off whenever nobody is touching the unit.
  - On while a volume button is pressed; fades out about 1 s after the last press.
  - A press while the speaker is muted shows a dim glow for about 2 s, so the user can tell it is muted.
  - Two short blinks if TALK is pressed while another room holds the channel, or while the mic is muted.
- **Per room:** green can be turned off in firmware for any room. The red glow can be dimmed further with its resistor, or left unpopulated in a room that should be fully dark, at the cost of losing the at-a-glance proof that the mic is off.
- Open question: in a bedroom where the mic stays muted, the red glow is on all night, however dim. A hardware-only alternative is a timed glow that lights for about 10 s after MIC MUTE or TALK is pressed (an RC timer on the latch output, no firmware involved).

**Power (in-wall): PoE over the Ethernet cable, and nothing else**

- Each in-wall endpoint is powered and connected by one Ethernet cable from a PoE switch (802.3af). There is no other power option for the in-wall endpoint: no local supply, no line voltage in or near the box, and no Wi-Fi.
- Why PoE only: the cable is low-voltage (Class 2), so it can run in the wall and into the box without the code problems of a 120 V supply. It gives wired sync and control, and one UPS on the switch backs up every in-wall endpoint.
- Budget: the ESP32-S3 with Ethernet plus a 3 W amp into 4 ohms. Plan for 5 V at 2 A at the endpoint, about 10 W. 802.3af provides up to about 13 W at the device, so it covers this.
- The PoE module on the board is the only supply. Do not plug in USB while PoE is connected; on the Waveshare board the two are not isolated from each other. For bench work, use one or the other.
- What it needs: a Cat5e or Cat6 run to each box and a PoE switch (or a PoE injector per run). This is the reason the in-wall endpoint suits new construction or a remodel.
- The tabletop endpoint is the answer where pulling cable is not practical (3.4).

**Mechanical**

The model is in `hardware/inwall/` (`inwall_endpoint.py`). Everything mounts to one printed carrier, so the whole endpoint can be built and tested on the bench, then screwed to the box as a unit.

- **Box:** a standard double-gang new-work box (Carlon B232A class: 4 in. wide, 3-3/4 in. tall, 3 in. deep). A reference model of the box is included for fit checks; it is not printed.
- The box doubles as the sealed speaker enclosure. Seal the cable entry, and put foam tape between the carrier and the wall so the enclosure stays closed.

| Printed part | What it does |
|---|---|
| Carrier | 112 x 108 x 3 mm plate that screws to the box's four device holes with 6-32 flat-head screws. Its back carries the driver seat and clamp bosses, the five button guide collars, button board standoffs, a mic pocket, and four posts for the sled. A groove in its front face holds the status LED behind the cloth |
| Sled | 94 x 87 mm plate that screws to the four posts, 35 mm behind the carrier, clear of the driver. A tray for the PoE ESP32 board with its RJ45 jack at the edge, a tray for the amp, zip-tie slots (including a pair to tie down the Ethernet cable), and wire pass-throughs |
| Cover | 117 x 113 mm wall plate, close to a standard double-gang plate. Held on by four pairs of 6 x 2 mm magnets, so no screws show. Speaker cloth is glued behind its 48 mm opening. Openings for the five caps and a mic port. No light window: the status glow shows through the speaker cloth |
| Button caps | Same moving-cap stack as the tabletop: guide collar, retaining flange, stem on a 6x6 tact switch. TALK is 32 x 16 mm; the other four are 14 x 11 mm |
| Driver ring | Clamps the 2 in. driver into its seat with four M2 screws |

- **Stack depth:** about 56 mm behind the wall surface to the top of the RJ45 jack and PoE module, in a box about 74 mm deep inside. That leaves about 18 mm behind the board.
- **Ethernet cable:** the plug enters the jack sideways, in the plane of the sled, and the model allows 12 mm for it. Terminate the in-wall cable with a plain unbooted plug, or use a short slim patch lead from a keystone jack, and tie the cable to the sled so the jack carries no strain.
- **ESP32 board:** use the version without header pins, or wire straight to the pads. The tray holds the board at its two ends so the pad rows stay clear.
- **Button board:** perfboard about 33 x 73 mm on four 10.25 mm standoffs.
- **Status LED:** lies in a 3.2 x 1.8 mm groove in the carrier's front face at the top of the speaker opening, with a wire hole through the carrier. The cover and the cloth sit over it.
- **Mic:** a round INMP441 breakout drops into the pocket and is held with a dab of glue. A foam ring between the carrier and the cover seals the port to the room.
- **Fit checks:** the generator checks every printed part and the driver, button board, and ESP32 against each other and against the box, and reports any overlap. The current model has none.
- **Service:** pull the cover off (fingernail notch at the bottom), remove four screws, and the whole endpoint comes out on its wires.

Hardware: 4 x 6-32 flat-head device screws (the box usually comes with them), 4 x M3 heat-set inserts and M3 x 6 screws for the sled, 4 x M2 heat-set inserts and M2 x 6 screws for the driver ring, 4 x M2 self-tapping screws for the button board, 8 x 6 x 2 mm magnets, 5 tact switches.

Verify against parts in hand: box interior size and the depth of its screw bosses, driver flange and basket size, INMP441 board diameter and port position, tact switch height, the height of the PoE board's RJ45 jack and PoE module (the model assumes 14 mm), and how far the Ethernet plug sticks out.

#### 3.1.2 Firmware

**Base**

- ESP-IDF.
- Music: community Snapcast client for ESP32 (CarlosDerSeher/snapclient). There is no official ESP32 Snapclient.
- Intercom: Opus decode/encode, UDP/RTP.
- Control: MQTT over TLS.

**State**

- `music_volume` (0-100)
- `music_mute` (bool)
- `intercom_volume` (0-100)
- `intercom_mute` (bool, "do not disturb")
- `system_override_volume` (0-100 or unset)
- `system_mute` (bool)
- `duck_level` (dB, for example -20 dB, or full mute)
- `priority_floor` (0-100, default 70): minimum playback level for a priority page
- `night_lock` (bool, per room): hard quiet that even a priority page respects
- `mic_muted` (bool, **read-only**): mirrors the hardware mute latch; firmware cannot change it
- `sound_mode` (`normal` or `background`, per room): see Background mode below
- `background_amount` (0-100, default 60): how far the background effect goes

**Button gestures**

| Gesture | Action |
|---|---|
| Hold TALK | Normal page to all rooms |
| Double-press TALK (tap, then press and hold within about 400 ms) | Priority page (see below) |
| VOL + / VOL - | Step `music_volume`; auto-repeat on hold |
| Hold VOL + and VOL - together about 0.75 s | Toggle `music_mute` (speaker only) |
| MIC MUTE | Toggle the hardware mic mute latch. Firmware sees the change but plays no part in it. |
| BACKGROUND | Toggle this room between normal sound and background mode. Software only, so the server can also set or reset it. |

A normal PTT starts on the first press, so the double-press gesture adds no delay to ordinary pages. A tap that is released quickly sends nothing.

If TALK is pressed while the mic is muted, the endpoint does not request the channel. It blinks green and plays a short local "mic is muted" chirp.

**Priority page**

- Sent with the double-press TALK gesture.
- Receiving rooms play it at `max(intercom_volume, priority_floor)`, so it overrides low volume settings.
- It breaks through `music_mute` and `intercom_mute`.
- It does not override `night_lock`. That is for rooms where nothing should ever play, such as a sleeping child's room.
- The controller keeps an allow-list of endpoints permitted to send priority pages, rate-limits them, and logs each one.

**Background mode ("music from the other room")**

A per-room sound setting for when music should be present but not in the way: dinner, reading, working, a conversation. It makes the music sound like it is playing in the next room. The effect runs on the endpoint, so one room can be in background mode while the rest of the house plays normally from the same stream.

What it does to the music, at the default amount:

| Stage | Setting | Why |
|---|---|---|
| Low-pass | 2nd order at about 2 kHz | Walls and doorways pass lows and block highs. This is most of the effect. |
| Presence cut | About -4 dB around 3 kHz | Keeps music out of the range where speech is understood, so it does not compete with conversation. |
| Low shelf | About +3 dB below 150 Hz | Keeps it warm instead of thin once the highs are gone. |
| Level | About -6 dB | Further away sounds quieter. |
| Compression | Gentle, about 2:1 | Holds a steady low level so loud passages do not jump out and quiet ones do not vanish. |
| Short reverb (optional, off by default) | Small room, about 0.3 s | Adds the diffuse sound of a far room. Costs the most CPU and memory, so it is opt-in. |

- `background_amount` scales the whole effect: 0 is normal sound, 100 is a heavy version (low-pass near 1 kHz, about -9 dB).
- Switching fades between the two filter sets over about half a second, so there is no click.
- Intercom pages, priority pages, and alarms bypass the effect. Voice always plays at full clarity.
- On the tabletop endpoint the low-pass sits below the crossover, so the tweeter goes nearly silent in this mode. That is expected.
- Set per room three ways: the BACKGROUND button on the endpoint, the web app, or a schedule (for example, background in the kitchen from 6 to 8 pm).
- The button and the server change the same setting, and the latest change wins:
  - If a schedule puts a room in background mode, anyone in the room can press BACKGROUND to hear normally, and press it again to go back.
  - A manual change holds until the next scheduled change for that room, or until someone changes it from the web app. The server can also reset rooms to a default at a set time (for example, everything back to normal at 6 am).
  - The endpoint reports every change over MQTT, so the web app always shows the real state.
- Feedback: the green glow shows twice briefly on entering background mode and once on leaving. The half-second fade in the sound is the main cue.
- After a power loss the endpoint asks the server for its current mode. If the server cannot be reached, it starts in normal mode.
- Cost: three or four extra biquads and a simple compressor per endpoint. Small for the ESP32-S3.
- HiFi endpoints (3.2, 3.3) can run the same filters in software on the Pi, for example with CamillaDSP.
- The values above are starting points to tune by ear on a built endpoint.

**Volume rules (in priority order)**

1. `system_mute` silences everything.
2. `night_lock` silences everything except `system_override_volume` alarms the room is subscribed to.
3. If `system_override_volume` is set (alarms, announcements), it applies to the override source only. It never raises music in a room above that room's `music_volume`.
4. A priority page plays at `max(intercom_volume, priority_floor)` and ignores `intercom_mute` and `music_mute`.
5. A normal page plays at `intercom_volume` unless `intercom_mute` is set. Whether it breaks through `music_mute` is a per-room setting (default: yes).
6. Music plays at `music_volume` unless `music_mute` is set, and drops by `duck_level` while intercom audio is playing.

All volume values map to gain on a dB curve (for example 0 to 100 maps to -60 dB to 0 dB, with 0 as true mute), not a linear scale.

**Tasks**

- **Network task**
  - In-wall: wired Ethernet (W5500 over SPI). Tabletop: Wi-Fi with reconnect.
  - Connects to Snapserver, the intercom multicast group, and the MQTT broker.

- **Audio mix and playback task**
  - Receives and decodes the Snapcast stream (FLAC, Opus, or PCM).
  - Receives and decodes intercom Opus packets.
  - Downmix to mono either in firmware `(L+R)/2` or in the MAX98357A via the SD pin.
  - Ducking is local: when intercom packets arrive, music gain ramps down by `duck_level` over about 50 ms; it ramps back up about 500 ms after the last intercom packet. No controller round trip.
  - Mixes both streams, applies gain, writes to I2S0 via DMA.

- **Intercom capture task**
  - On PTT press: if `mic_muted`, refuse locally (see gestures). Otherwise request the channel (normal or priority) from the intercom server. If granted, mute local speaker output, wait for mic startup, capture from I2S1, encode Opus, transmit.
  - If denied: blink busy indication, do not transmit.
  - On PTT release: stop transmit, release channel, restore local speaker.

- **Button and LED task**
  - Debounce all five buttons and decode the gestures above.
  - VOL_UP / VOL_DOWN: step `music_volume` (for example 5 per press).
  - Drive LED per the behavior above and per-room LED policy.

- **Control and telemetry**
  - Accepts commands only over authenticated MQTT.
  - Commands: set music/intercom volume and mute, set sound mode and background amount, set or clear system override, set system mute, set per-room policy. There is no command for the mic mute; it exists only as a button.
  - Reports: online status, PTT events, volume and mute state, `mic_muted`, firmware version, errors.
  - Signed OTA updates.

---

### 3.2 HiFi endpoint (Pi Zero 2 W + stereo speakers)

**Use case:** rooms where music quality matters more than in-wall simplicity.

**Hardware**

- Raspberry Pi Zero 2 W (or Pi 3/4 if wired Ethernet is wanted without an adapter).
- Stereo DAC/amp HAT (HiFiBerry MiniAmp for small speakers, HiFiBerry Amp2/Amp4 for larger passive speakers), or a DAC HAT feeding powered speakers.
- Pair of in-wall, in-ceiling, or bookshelf speakers matched to the amp.

**Software**

- Snapclient for music.
- Intercom client for receive. A USB or I2S mic plus a PTT button can be added if the room needs to page.
- Same MQTT control model and volume rules as the ESP32-S3 endpoints.

### 3.3 HiFi system endpoint (existing stereo or AVR)

**Use case:** living room or other space with an existing receiver.

**Hardware**

- Raspberry Pi with a DAC HAT (or USB DAC) feeding an AVR analog or digital input.

**Software**

- Snapclient for music.
- Intercom receive optional. If enabled, the AVR must be on and set to the right input for pages to be heard. HDMI-CEC or IR control can switch it.

### 3.4 Tabletop endpoint (desktop, USB-C, battery-backed)

**Use case:** rooms where an in-wall box is not practical (rentals, desks, nightstands, the shop), or where the endpoint should stay up through a power blip.

This is the reference build. It uses the shared electronics and firmware described in 3.1.1 and 3.1.2, in a printed desktop enclosure with a folded transmission line, USB-C power, and a battery that carries it through outages.

#### 3.4.1 Form factor

- Low slab, small-router style.
- Outer size: **250 W x 173 D x 84 H mm** (base 81 mm + 3 mm lid). Fits the A1's 256 x 256 mm bed.
- Height is set by the front-firing 2.5 in. woofer (70 mm square frame) and its magnetic grille ring. The tweeter fits beside it without changing the box size.
- Layout, viewed from the front:
  - Left three quarters: transmission line, with the woofer and a small tweeter side by side in a recess on the front face, behind one removable cloth grille.
  - Right third: electronics bay (amp, ESP32-S3, battery, charger), mic port on the front face, five button caps in the lid above.
- The top shows only the five button caps: no screws or other hardware. The lid is held by six M3 screws that come up through the bottom, where the four adhesive feet also go.
  - Rear: line mouth slots and USB-C power.

#### 3.4.2 Acoustic design: folded transmission line

The back wave of the driver loads a folded, tapered quarter-wave line (the same idea as the Bose Wave waveguide, at a much smaller scale). The line reinforces output around its quarter-wave frequency, which lifts the low end of a small driver that rolls off quickly below its resonance. It will not make deep bass from a 2.5 in. driver, but with the line tuned near the driver's 109 Hz resonance it gives voices real body and background music a usable low end.

| Parameter | Value |
|---|---|
| Driver | Dayton Audio CE70PR-4, 2.5 in. (Fs 109 Hz, Qts 0.63, Vas 0.52 L, Sd 24.6 cm2, Xmax 4.0 mm, 85 dB, 38.6 mm deep, 41.2 mm with terminals) |
| Line type | Offset-driver, tapered quarter-wave line, folded into 4 legs |
| Internal height | 78.6 mm |
| Leg widths | 53 / 42 / 36 / 31 mm |
| Cross-section | 41.7 / 33.0 / 28.3 / 24.5 cm2 (about 1.7 x Sd tapering to 1.0 x Sd) |
| Centerline length | about 730 mm (about 750 mm with mouth end correction) |
| Quarter-wave tuning | about 115 Hz, just above driver Fs |
| Driver offset | about 135 mm from the closed end (18 percent of line length; offset position helps suppress the line's 3rd harmonic peak) |
| Line volume | about 2.4 L |
| Mouth | Vertical slots in the rear wall near the end of leg 4, about 50 mm wide, open area about equal to the leg 4 cross-section |

Why this driver (compared with the 2 in. CE52N-4 used earlier):

- About 9 times the displacement before it runs out of travel (Xmax 4.0 mm vs 0.85 mm, twice the cone area).
- Resonance 109 Hz instead of 164 Hz, so the line tunes half an octave lower.
- Same 85 dB sensitivity, so the 3 W amp drives it just as loud. Power and battery are unchanged.
- Qts 0.63 suits a transmission line. The 3 in. CE78PF-4 was rejected: its Qts of 0.99 makes a line boomy, and its 1.4 mm Xmax gives up most of the size advantage.
- Trade-off: top end rolls off around 13 kHz. Fine for voice and background music.

Construction details:

- The closed end of the line is at the separator wall (right end of leg 1). The driver sits toward the left end of leg 1, so a short closed stub sits behind it on one side and the long line runs out the other.
- Turns use 45 degree deflectors at the outer corners to reduce reflections. The front-left corner of leg 1 is left square because the driver recess sits there.
- The lid has 1.2 mm grooves that the line walls and separator wall seat into. Run a thin bead of silicone or 1 mm foam tape in the grooves at assembly so the legs are sealed from each other. Leaks between legs shorten the effective line.
- Damping: lightly stuff the closed stub and the first half of leg 1 with polyfill. Start with about 6 to 8 grams and tune by ear and measurement. More stuffing smooths the midrange ripple and lowers output at the tuning frequency.
- Tuning knobs if it needs adjustment after measuring: leg widths (taper), stuffing amount, and mouth open area. All are parameters in the generator script.
- Firmware EQ: a gentle high-pass around 80 to 90 Hz keeps the driver from wasting excursion below the line's useful range.

**Tweeter**

- Dayton Audio ND16FA-6, 5/8 in. neodymium soft dome: 6 ohm, Fs 2125 Hz, 88 dB, response 3.5 to 27 kHz, 32.5 mm faceplate, 25 mm cutout, 14.5 mm deep.
- Sits to the right of the woofer at the same height, 53 mm center to center. That spacing is well under one wavelength at the crossover frequency, so the two drivers blend cleanly.
- It is a sealed-back dome, so it can sit in leg 1 of the line without its back wave mattering.
- The crossover, levels, and time alignment are all done in software on the ESP32-S3 (see 3.4.3, Audio processing). There is no passive crossover.

**Driver mounting and grille**

- The front face has a 129 x 76 mm rounded-rectangle recess, 4.5 mm deep, in front of both drivers. The baffle at the bottom of the recess is 5 mm thick.
- The driver mounts from the front with no printed grillwork in the way. Its 70 x 70 mm square frame (R7 corners) drops into a 3 mm counterbore so the frame face is flush with the recess floor. The baffle cutout is 64 mm.
- Four M4 screws through the frame's corner holes (4.2 mm holes on a 79 mm circle, a 55.9 mm square pattern) thread into M4 heat-set inserts in bosses behind the baffle.
- The tweeter faceplate drops into a 33 mm counterbore (3 mm deep) so it is flush with the recess floor, and is held with a thin bead of silicone or a ring of VHB tape. The ND16FA-6 has no screw holes.
- **Grille ring:** a separate 4.5 mm thick printed frame that sits in the recess, flush with the front face. Its opening is one smooth shape that wraps both drivers (a 64 mm circle over the woofer blending into a 30 mm circle over the tweeter). One piece of speaker cloth is hot-glued to its back in a 0.6 mm deep land 5 mm wide around the opening.
- **Magnets:** four 6 x 3 mm disc magnets in the back of the ring meet four in the recess floor: two beside the woofer at the left end, two beside the tweeter at the right end, all outside the driver frames. Glue them in with matched polarity (mark one face of each magnet before gluing, and test-fit the ring before the glue sets).
- A small pry notch at the bottom edge of the recess lets you get a fingernail behind the ring to pull it off.
- Speaker cloth: thin, acoustically transparent grille cloth. Stretch it tight before gluing so it does not buzz.

#### 3.4.3 Electronics

Same as the shared electronics in 3.1.1 unless noted.

- **MCU:** ESP32-S3-DevKitC-1 (N8R8). Wi-Fi, since the tabletop unit has no Ethernet. The DevKitC has no mounting holes, so it sits on ledges in a tray with snap lips.
- **Amps:** two MAX98357A breakouts on one I2S bus. The SD pin selects the channel on each board: one plays the left slot (woofer), the other the right slot (tweeter). Both sit on trays at the front of the bay. Speaker leads run through a small pass-through in the separator wall, then along the floor of leg 1 to the drivers. Seal the pass-through with hot glue or silicone after wiring.
- **Tweeter protection:** a 10 to 22 uF film capacitor in series with the tweeter. The software crossover normally keeps bass out of the tweeter, but this blocks it in hardware too, in case of a firmware fault, a turn-on thump, or a bad filter setting. Size it so its corner is well below the crossover (about 1 to 1.5 kHz with the 6 ohm tweeter).
- **Mic:** INMP441 module, sealed to a 2.6 mm front port with a foam gasket, held in slide rails. Powered through the mic privacy circuit in 3.1.1 (PTT and the mute latch, both in hardware).
- **Buttons:** five separate printed button caps in openings in the lid, over the electronics bay. Each cap moves; nothing about the lid flexes.

| Button | Cap size | Center (x, y from front-left) | Cap top mark |
|---|---|---|---|
| TALK | 40 x 24 mm | (218.6, 26.0) | shallow dish, about 11 mm across |
| VOL - | 18 x 14 mm | (206.1, 58.0) | engraved minus |
| VOL + | 18 x 14 mm | (231.1, 58.0) | engraved plus |
| MIC MUTE | 18 x 14 mm | (206.1, 86.0) | engraved ring with a slash |
| BACKGROUND | 18 x 14 mm | (231.1, 86.0) | three engraved bars, fading in length |

  - Three rows, front to back: TALK (largest, nearest the front edge), then VOL - and VOL +, then MIC MUTE and BACKGROUND. The two back pairs are the same size and line up under each other, and each pair spans the width of TALK.
  - MIC MUTE and BACKGROUND are told apart by their marks and by the red mute light. Pressing the wrong one is harmless: mute only ever turns the mic off or back to push-to-talk, and background only changes the sound.
  - Stack, top to bottom: cap top 0.6 mm above the lid surface; cap body through the 3 mm lid and a 4 mm guide collar (0.3 mm clearance per side, chamfered opening at the top); a 1.5 mm retaining flange under the collar; a 4 mm stem that rests 0.05 mm above the tact switch actuator.
  - The tact switch is the return spring. At rest the switch pushes the cap up until the flange meets the collar. Pressing moves the cap about 0.3 mm to the click.
  - Caps drop into the openings from below before the button board is installed, so they are captive with no visible fasteners.
  - Button board: perfboard about 54 x 91 mm on four 10.25 mm lid standoffs (M2 holes at 49 mm across, rows at y = 15.5 and 99.0 mm). Switch actuator tops must sit at 75.75 mm above the bottom of the base, which the standoff length sets for a 5.0 mm tall switch. Switch positions on the board match the cap centers above.
  - If the switches in hand are a different height, change `SWITCH_H` in the generator and re-run; the standoff length follows.
- **Audio processing (on the ESP32-S3):** the decoded stream is processed per sample block before it goes to the I2S amps:

```
Snapcast stereo -> mono downmix -> background mode (if on) -+-> room/driver EQ (parametric) -> crossover, LR4 at about 4.5 kHz
Intercom Opus  -> ducking mix (bypasses background mode)  -+       |                                  |
                                          woofer: high-pass 80-90 Hz,      tweeter: level trim (about -3 dB),
                                          volume-dependent bass boost,     small delay for time alignment
                                          limiter                          (about 2 samples at 48 kHz)
                                          -> I2S left slot (woofer amp)    -> I2S right slot (tweeter amp)
```

  - Crossover: 4th-order Linkwitz-Riley at about 4.5 kHz, a little over twice the tweeter's 2125 Hz resonance. The woofer is still clean there (it runs to 13 kHz).
  - Level: the tweeter is about 3 dB more sensitive than the woofer, so it is trimmed down.
  - Bass boost tracks volume (more boost at low volume, backing off as volume rises) and the limiter keeps the woofer inside its 4 mm excursion. This is the same approach that makes small commercial smart speakers sound bigger than they are.
  - All settings are biquad coefficients stored in flash and adjustable over MQTT, so the endpoint can be tuned after it is built.
  - Tuning method: measure each driver in the finished box with a measurement mic (for example a miniDSP UMIK-1 with the free REW software), set the EQ and crossover from the measurements, and save the result as the endpoint's profile.
  - CPU: about 20 biquads at 48 kHz is a small load for the S3 using Espressif's esp-dsp library.
- **Status light:** indirect, behind the grille cloth (see Status light in 3.1.1). A 3 mm bicolor LED pushes into a 3.2 mm hole in the recess floor 20 mm above the tweeter centre, where the solid frame of the grille ring covers it. A hooded channel in the back of the ring lets the light spill sideways into the grille opening. Seal the LED into its hole with glue so the transmission line stays closed. There is no light window on any face of the enclosure.

#### 3.4.4 Power, battery backup, and hum

**Power path**

```
USB-C 5 V in -> power-path Li-ion charger -> 1S 18650 cell
                        |
                        +-> system rail (3.6-4.4 V) -> 5 V synchronous boost (2 A class) -> ESP32-S3 5V pin, MAX98357A VDD
```

- The charger must be a **power-path (load sharing)** type, such as a TI BQ24074-based board. With power path, the system runs from USB when it is present and from the battery the instant it is not, with no switchover gap and no reboot. Avoid cheap "power bank" modules (IP5306 class): many shut off at light load or glitch during switchover.
- Boost to 5 V so the amp keeps its full output on battery. Size it for the amp's peak current (about 0.8 A into 4 ohms at full output) plus the ESP32's Wi-Fi peaks.
- Sense lines to the ESP32: USB present (VBUS through a divider) and battery voltage (ADC through a divider).

**Runtime**

| Case | System draw | Runtime on one 2500 mAh 18650 (about 9 Wh, 85 percent boost efficiency) |
|---|---|---|
| Idle on Wi-Fi, no audio | about 0.5 W | about 15 hours |
| Background music | about 1.0 W | about 7 hours |
| Loud, continuous | about 2.5 W | about 3 hours |

The 10 to 15 minute requirement is met with a large margin. A smaller LiPo pouch would also meet it, but an 18650 costs about the same and gives hours.

**Behavior on power loss**

- Endpoint reports `on_battery` over MQTT and keeps running.
- Optional: cap music volume while on battery to stretch runtime. Intercom and alerts stay at normal volume.
- Below a low-battery threshold, report `battery_low`, then shut down cleanly before the charger's cutoff.
- The endpoint staying up is only useful if the Wi-Fi access point, switch, and Pi controller are on a UPS too. Plan that as part of this feature.

**Hum and isolation**

- The audio path is digital all the way to the amp (I2S into the MAX98357A), so there is no analog line for 60 Hz to couple into.
- A USB-C wall charger is already galvanically isolated from the AC line. No extra isolation stage is needed.
- Hum in small powered speakers usually comes from one of three things, and this design avoids each:
  - **Ground loops:** need two grounded connections with an analog link between them. This unit has one power input and no analog audio connections.
  - **Noisy chargers:** cheap chargers leak switching and common-mode noise. Use a UL-listed, two-prong (Class II) charger from a known brand. The battery-buffered power path also smooths what gets through.
  - **Supply ripple at the amp:** add a ferrite bead and a 470 uF low-ESR capacitor at the amp's VDD, run a star ground, keep the boost converter away from the speaker leads, and keep the speaker leads short and twisted.

#### 3.4.5 Enclosure and printing (Bambu Lab A1)

**Parts**

| Part | Print orientation | Supports | Notes |
|---|---|---|---|
| `base.stl` | Floor on the bed, open side up | None | Line walls, separator wall, trays, rails, and bosses all print vertically. The front recess, driver cutouts, and mouth slots are open shapes that need no support. |
| `lid.stl` | Top face on the bed | None | Grooves, lip, standoffs, guide collars, and the six 75 mm pillars point up. |
| `button_caps.stl` | Cap tops on the bed (all five on one plate) | None | Touch marks print on the smooth bed side. The flange underside is a 45 degree chamfer, so it needs no support. |
| `grille_ring.stl` | Front face on the bed | None | Magnet pockets, the cloth land, and the hooded light channel face up. |

All parts fit the A1's 256 x 256 mm bed. The base (250 x 173 mm) is the largest; leave the bed's default margins and center it.

**Material and settings**

- **PETG.** The A1 is an open-frame printer, so ASA and ABS will warp at this size.
- 0.4 mm nozzle, 0.2 mm layers. The 2.4 mm walls print as solid perimeters; set wall loops high enough (6 at 0.42 mm line width) that the walls have no infill gaps, which keeps them stiff and acoustically dead.
- Caps: test-fit one cap in its opening before printing the full lid. If it binds, raise `CAP_CLEAR`; if it rattles, lower it.
- Lid pillars are 75 mm tall and 9 mm across. They print fine in PETG on the A1, but slow the outer walls a little for the top half of the pillars if they wobble, since the bed moves under them.
- Expect roughly 450 to 500 g of PETG for the base and about 190 g for the lid.
- Print one cap and a small test piece of the lid (one opening with its collar, one pillar end) to check cap fit and insert fit before committing to the full lid.

**Hardware**

| Item | Qty | Use |
|---|---|---|
| M3 heat-set insert, 4.0 mm bore, 6 mm deep | 6 | Ends of the lid pillars |
| M3 x 8 socket head screw | 6 | Up through the bottom into the pillars (counterbored, heads sit below the surface) |
| Dayton Audio CE70PR-4 woofer | 1 | Front recess |
| Dayton Audio ND16FA-6 tweeter | 1 | Beside the woofer |
| 3 mm bicolor LED (red/green) | 1 | Status glow, in the recess floor above the tweeter |
| MAX98357A breakout (second) | 1 | Tweeter channel |
| 10 to 22 uF film capacitor | 1 | In series with the tweeter |
| M4 heat-set insert, 5.6 mm bore, 6 mm deep | 4 | Driver mounting bosses behind the baffle |
| M4 x 10 pan or button head screw | 4 | Driver, through the frame corner holes |
| 6 x 3 mm neodymium disc magnet | 8 | Grille ring (4) and recess floor (4) |
| Acoustic grille cloth, about 120 x 70 mm | 1 | Hot-glued to the back of the grille ring |
| M2 x 5 self-tapping screw | 4 | Button perfboard to lid standoffs |
| 12 mm self-adhesive bumper feet | 4 | Foot rings in the bottom (0.8 mm deep seats) |
| 6x6 mm tact switch | 5 | TALK, VOL -, VOL +, MIC MUTE, BACKGROUND |
| Foam gasket tape (1 mm) | 1 | Under the driver frame, and the mic port |
| Polyfill | a few grams | Line damping |
| Small zip ties | 2 | Battery holder strap |

**Assembly order**

1. Install heat-set inserts: 6 x M3 in the lid pillar ends, 4 x M4 in the driver bosses.
2. Glue the magnets into the recess floor and the grille ring (matched polarity). Glue the cloth to the ring.
3. Run the speaker leads from the bay through the pass-through and out the driver cutout. Solder them to the woofer, put gasket tape on the frame, and screw it in from the front. Wire the tweeter (with its series capacitor) and seat it in its counterbore with silicone or VHB.
4. Seal the pass-through.
5. Add polyfill to the closed end and leg 1.
6. Fit the amps, ESP32, charger, battery holder, USB-C breakout, and mic module. Push the status LED into its hole above the tweeter from inside and seal it with glue.
7. Turn the lid over, drop the five caps into their openings, and screw the button board onto the standoffs. The board holds the caps in.
8. Run silicone or foam tape in the lid grooves, set the lid on (the pillars drop into the floor sockets), flip the unit, and drive the six screws up through the bottom.
9. Stick the four bumper feet in the foot rings, and press the grille ring into the recess.
10. Before closing: continuity-check that no ESP32 GPIO connects to the mute latch inputs or either mic load switch enable.

#### 3.4.6 Open items

- **Mic privacy board:** lay out the latch, series load switches, Ioff buffer, and LED driver on the button board or a small daughterboard, and confirm the power-up-muted behavior.
- **Verify against parts in hand:** CE70PR-4 frame thickness (counterbore is 3.0 mm) and basket diameter at the baffle (cutout is 64 mm; the spec sheet shows 60 to 63.8); ND16FA-6 faceplate thickness (counterbore is 3.0 mm); INMP441 board width and thickness; 18650 holder footprint (pocket is 21.1 x 78.1 mm); tact switch height (board standoffs assume 5.0 mm); USB-C breakout board width (frame is 15 mm).
- **Charger and boost:** pick specific boards and update the tray size (charger tray is 26 x 22 mm).
- **Measure the line:** in-box frequency response near field at the driver and at the mouth, then adjust stuffing and taper.
- **Tuning range:** the line is about 115 Hz in a box that fits the A1 bed. Going lower needs a fifth leg (deeper box) or a printer with a bigger bed.

**Source:** `tabletop_endpoint.py` generates all four STLs. Every dimension above is a named parameter at the top of the script.

---

## 4. Audio and sync model

- Music: Snapcast. All clients play the same stream with synchronized timing. Snapcast buffer latency is accepted for music.
- Intercom: separate low-latency multicast Opus stream. Not synchronized across rooms; latency matters more than tight sync for voice.
- Ducking and mixing happen on each endpoint, so music and intercom are independent at the server.
- Alarms and announcements: played as a Snapserver stream (synchronized) with a system volume override.

## 5. Mechanical design notes for HiFi endpoints

- Pi and amp HAT mounted in a low-voltage location (closet, media cabinet, or ventilated in-wall enclosure) with speaker wire run to the speakers.
- Ventilation required for the amp HAT under sustained load.
- Use in-wall-rated (CL2 or CL3) speaker wire for any run inside walls.

## 6. Software architecture summary

| Component | Runs on | Purpose |
|---|---|---|
| Plex Media Server (Plex mode) | Pi 5 or another LAN machine | Music library (2.4) |
| Plexamp headless (Plex mode) | Pi 5 | Plex player that feeds Snapserver through an ALSA loopback (2.4) |
| MPD (share mode) | Pi 5 | Plays from a network share into Snapserver; controlled from the web app or any MPD client (2.4) |
| Snapserver | Pi 5 | Synchronized music |
| Intercom server | Pi 5 | PTT arbitration and Opus relay |
| Mosquitto | Pi 5 | Authenticated endpoint control |
| Web app (Flask/FastAPI) | Pi 5 | UI, schedules, API |
| Scheduler | Pi 5 | Alarms and announcements |
| Endpoint firmware | ESP32-S3 (tabletop and in-wall) | Playback, mix, duck, background mode, PTT capture, controls |
| Same firmware, tabletop build | ESP32-S3-DevKitC-1 | As above, on Wi-Fi, with battery and USB-present reporting and the two-way crossover |
| Same firmware, in-wall build | ESP32-S3 with Ethernet and PoE | As above, on wired Ethernet, single driver |
| Snapclient + intercom client | HiFi endpoints | Playback and optional paging |
| Remote intercom gateway (Pion or aiortc) | Pi 5 | WebRTC to phones, bridged to the house intercom (2.3) |
| Rendezvous server (signaling, coturn, push) | Cloud VPS, rendezvous mode only | Connects phones and the Pi; sees only encrypted media (2.3) |
| Holler app for iPhone (Swift, WebRTC, PushToTalk) | iPhone | Remote paging and hearing pages (2.3) |
| Holler app for Android (Kotlin, WebRTC, FCM) | Android phone | Remote paging and hearing pages (2.3) |

## 7. Future extensions

- Room-to-room calls (direct routing instead of all-call).
- Home Assistant integration through MQTT.
- Doorbell and alert integration (play chime and TTS to all rooms).
- Per-room source selection (different music in different zones).
- A timed mic-mute glow for bedrooms (hardware timer; see the open question under Status light in 3.1.1).
- A hidden press zone cover for the in-wall endpoint, as an alternative to moving caps.

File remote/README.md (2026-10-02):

# Holler remote intercom

Not started. See docs/design.md, section 2.3.

| Folder | Runs on | Job |
|---|---|---|
| `gateway/` | Pi 5 | WebRTC audio to phones, bridged to the house intercom |
| `rendezvous/` | Cloud VPS | Signaling, TURN relay (coturn), push. Untrusted: never holds media keys. Rendezvous mode only |
| `ios/` | iPhone | Push-to-talk app (Swift, WebRTC, PushToTalk framework) |
| `android/` | Android phone | Push-to-talk app (Kotlin, WebRTC, foreground service, FCM) |

Two ways for a phone to reach the house:

- **Rendezvous mode (default):** the Pi and the phone both connect out to the rendezvous server. No inbound port at home.
- **Direct mode (lower security):** the router forwards two ports to the gateway. No hosted server, but a service at home is exposed to the internet.

Pairing, signed setup messages, and end-to-end audio encryption are the same in both.

Build order: a LAN-only web paging page served by the gateway first, then rendezvous mode and one native app, then the second app and direct mode.

Remote access covers the intercom only, not music or house controls.

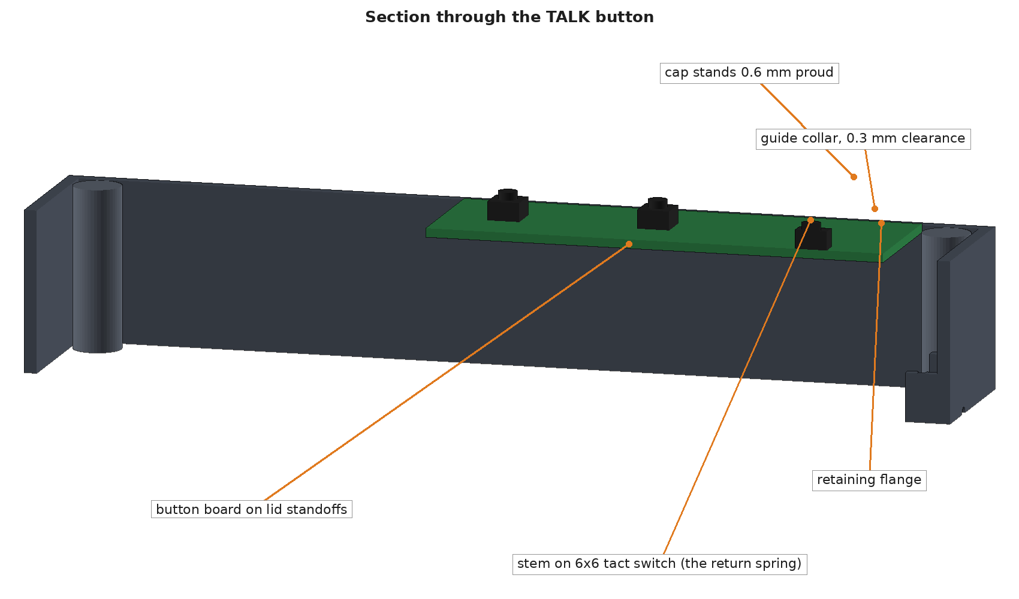
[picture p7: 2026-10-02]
hardware/tabletop/renders/render_button_section.png

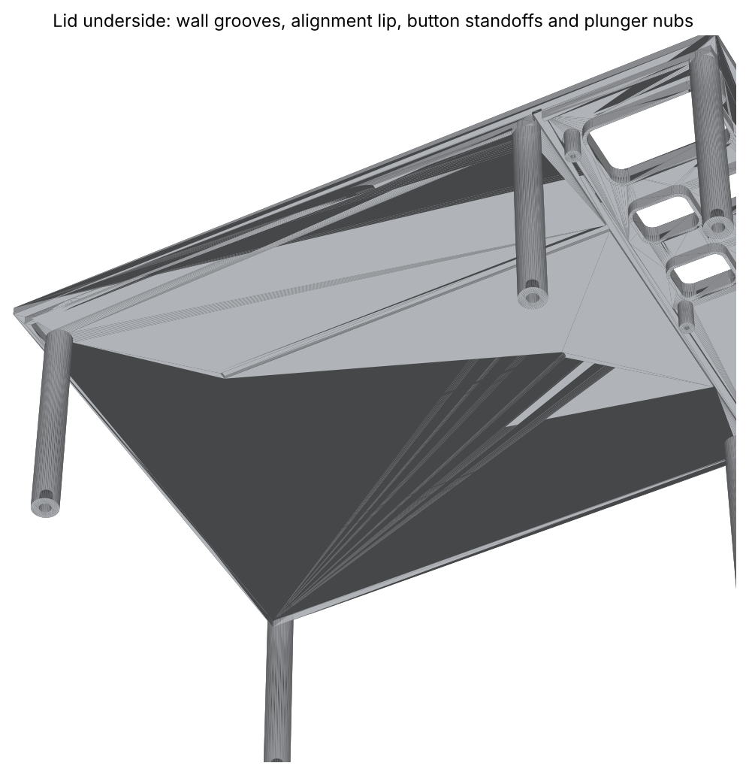
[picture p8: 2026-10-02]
hardware/tabletop/renders/render_lid_under.png

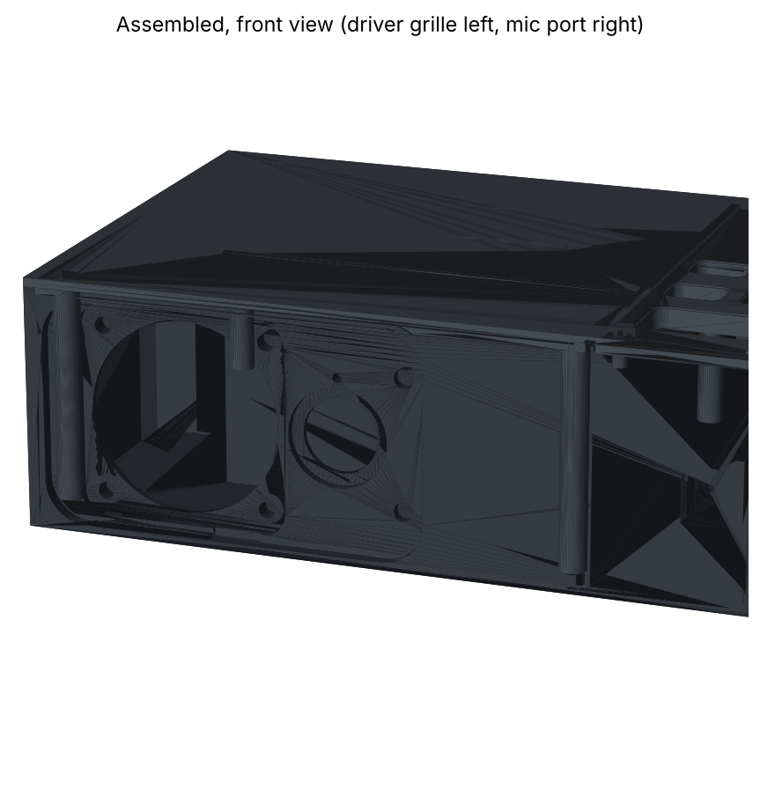
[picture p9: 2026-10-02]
hardware/tabletop/renders/render_front.png

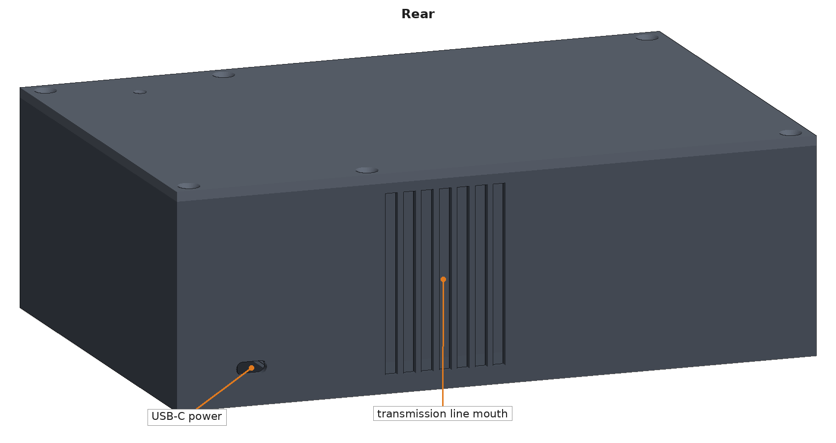
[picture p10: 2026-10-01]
hardware/tabletop/renders/render_rear.png

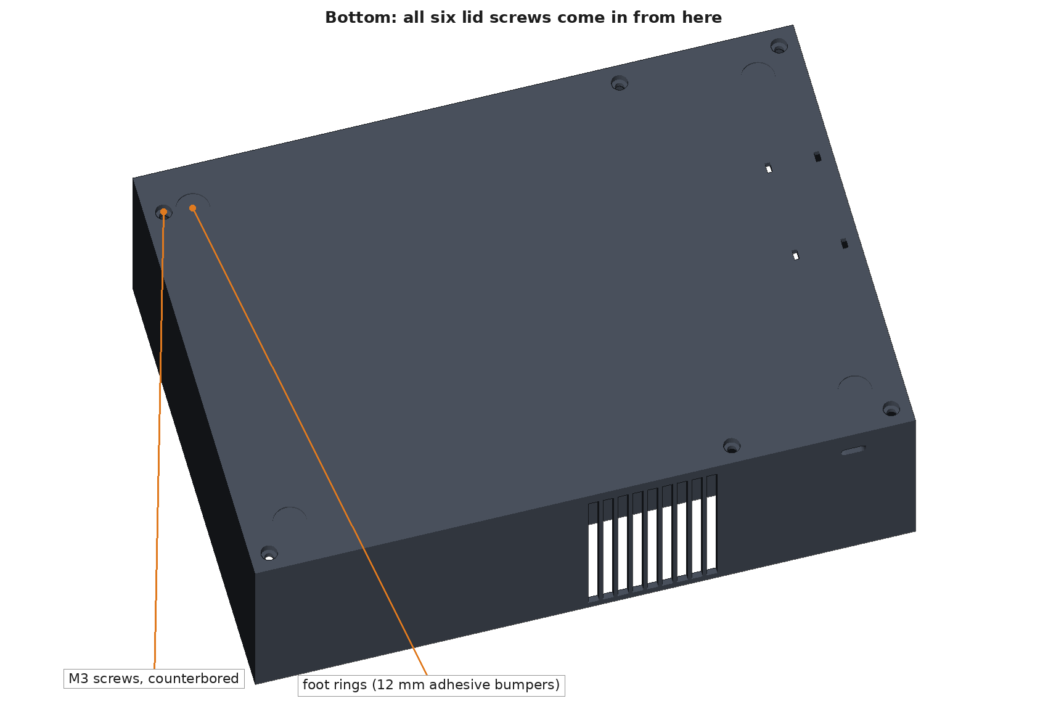
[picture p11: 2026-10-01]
hardware/tabletop/renders/render_bottom.png

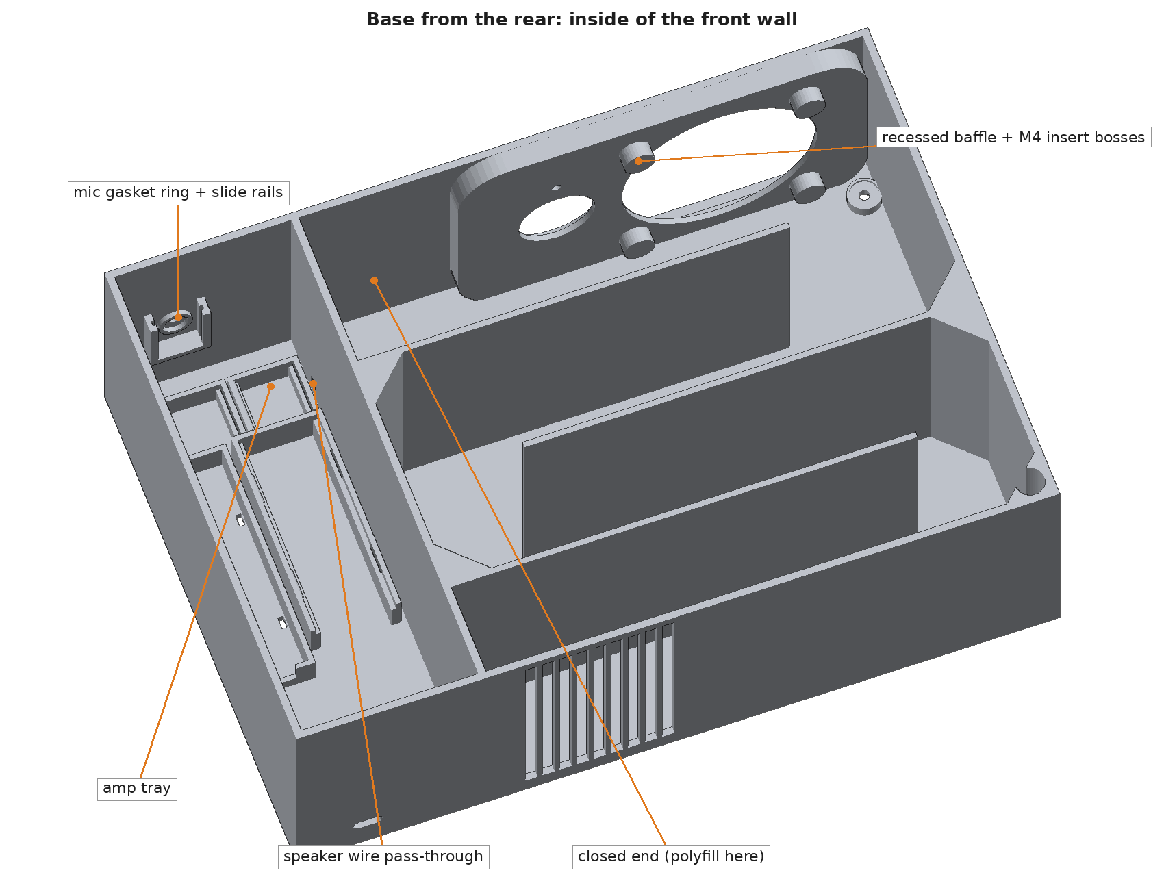
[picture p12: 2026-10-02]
hardware/tabletop/renders/render_base_front_inside.png

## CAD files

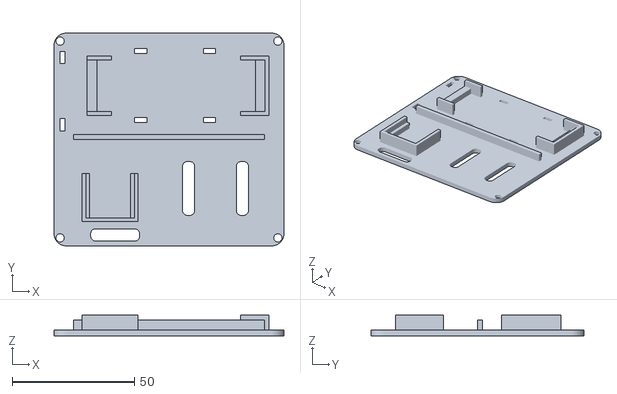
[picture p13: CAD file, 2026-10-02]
hardware/inwall/sled.stl
94.0 x 87.0 x 8.39

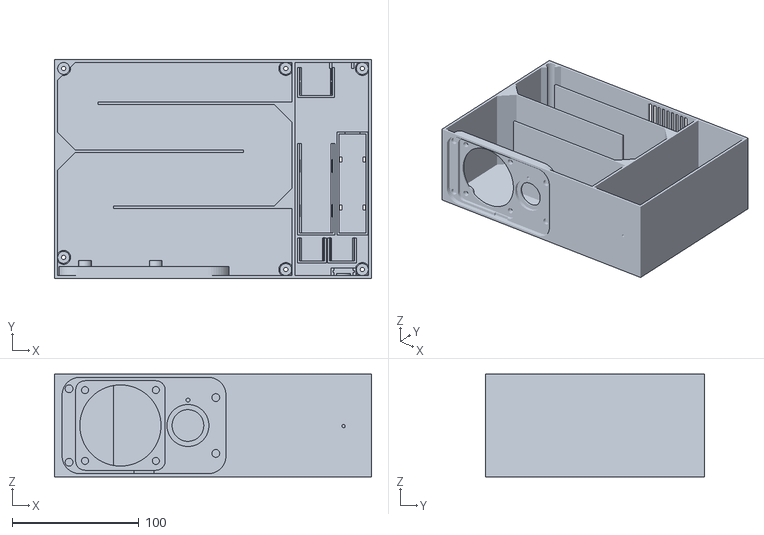
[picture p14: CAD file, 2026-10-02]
hardware/tabletop/base.stl
250.0 x 173.0 x 81.0

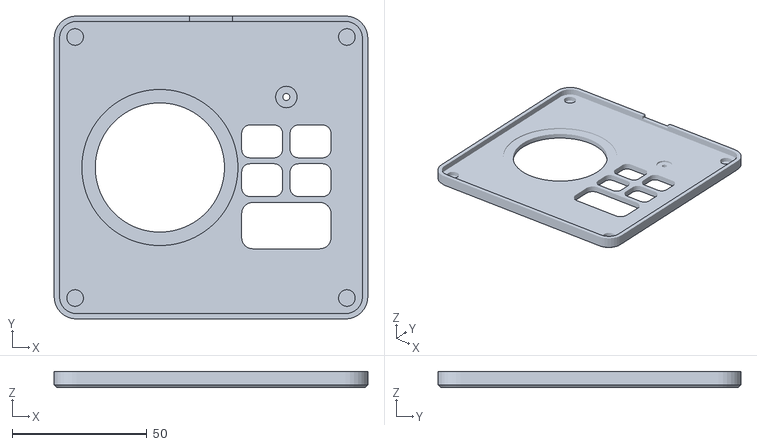
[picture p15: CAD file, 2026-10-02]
hardware/inwall/cover.stl
116.6 x 112.6 x 6.00

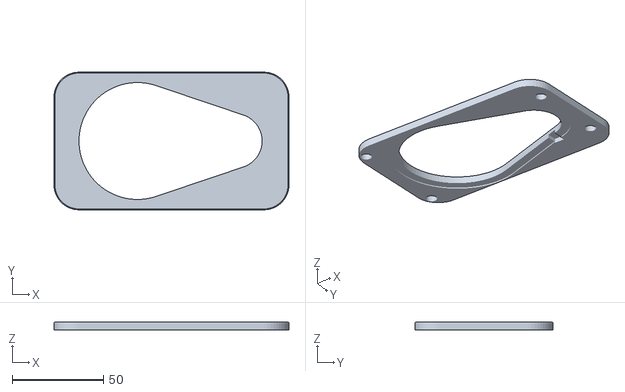
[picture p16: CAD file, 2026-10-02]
hardware/tabletop/grille_ring.stl
128.6 x 75.4 x 4.50

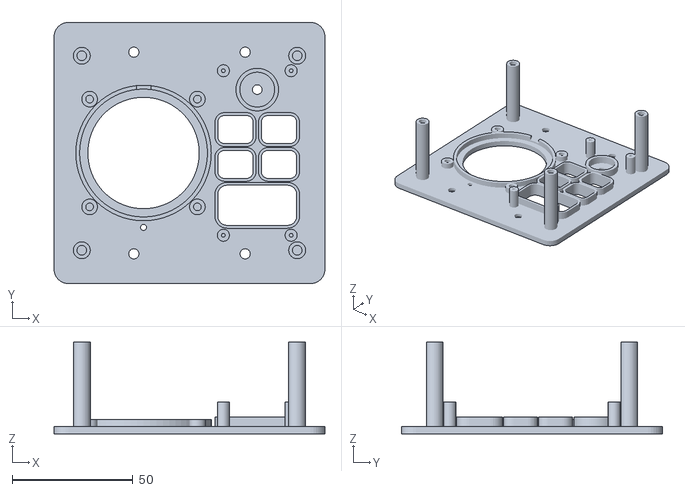
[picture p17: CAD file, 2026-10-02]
hardware/inwall/carrier.stl
112.0 x 108.0 x 38.0

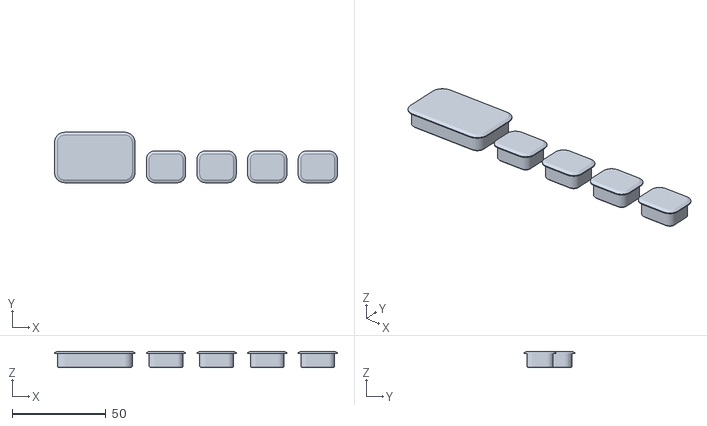
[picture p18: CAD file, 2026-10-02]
hardware/tabletop/button_caps.stl
151.0 x 27.0 x 8.80

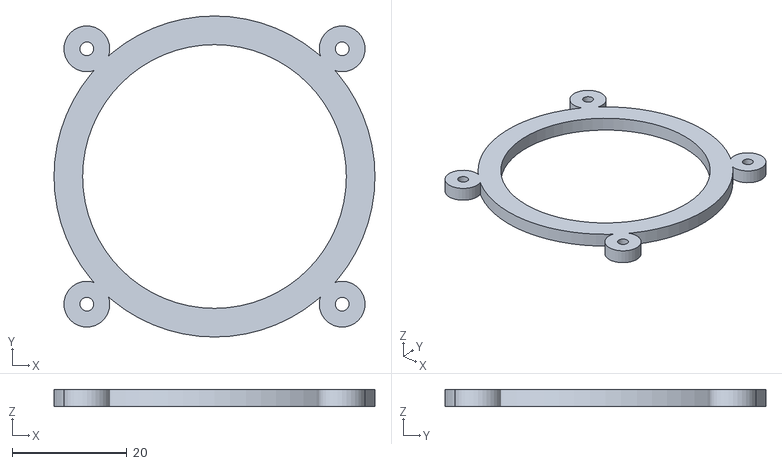
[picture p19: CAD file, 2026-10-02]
hardware/inwall/driver_ring.stl
56.0 x 56.0 x 3.00

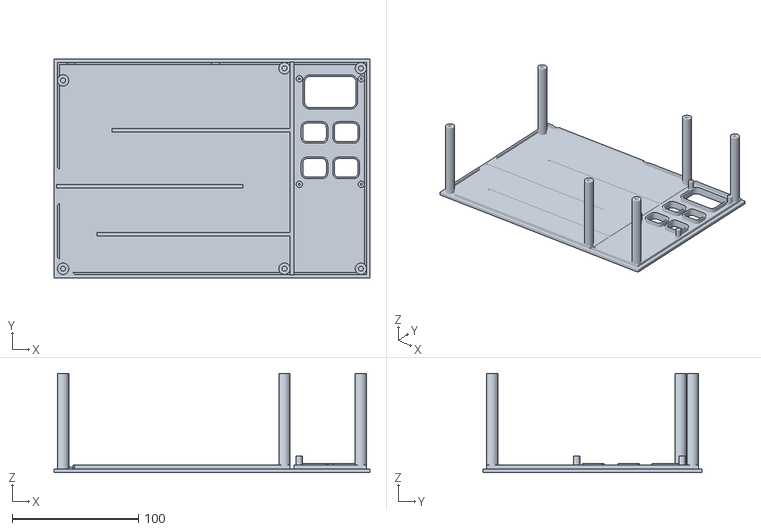
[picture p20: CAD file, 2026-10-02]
hardware/tabletop/lid.stl
250.0 x 173.0 x 78.4

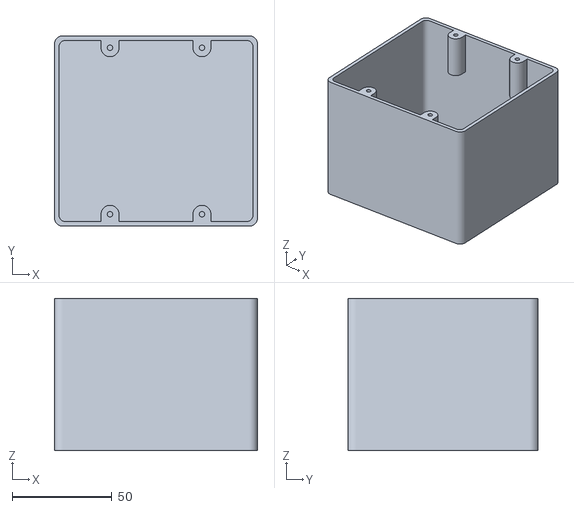
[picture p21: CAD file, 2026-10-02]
hardware/inwall/box_reference.stl
101.6 x 95.2 x 76.2

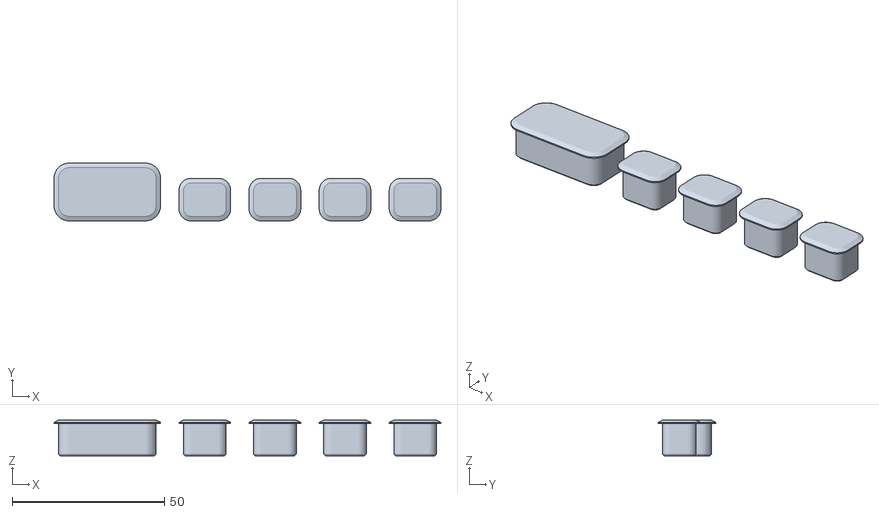
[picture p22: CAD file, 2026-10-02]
hardware/inwall/button_caps.stl
127.0 x 19.0 x 11.8

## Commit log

2026-10-01 Initial commit: design doc and tabletop endpoint enclosure
    - docs/design.md: full system design (controller, endpoints, mic privacy
    circuit, tabletop endpoint, remote intercom)
    - hardware/tabletop: parametric enclosure generator, printable STLs,
    preview renders
    - READMEs for firmware, controller, and remote intercom (not started)
    Claude-Session: https://claude.ai/code/session_011vYEgnES57SmJcMte2QXM3
    [base.stl, button_caps.stl, grille_ring.stl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]
2026-10-02 Add share mode for music and a per-room background sound mode
    - docs/design.md 2.4: two music modes, Plex (Plexamp headless) or a
    network share played by MPD, each feeding Snapserver
    - docs/design.md 3.1.2: background mode, a per-room "music from the
    other room" filter that pages and alarms bypass
    - README and controller README updated to match
    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
2026-10-02 Add a BACKGROUND button beside MIC MUTE on the tabletop endpoint
    - Enclosure: fifth button cap; MIC MUTE and BACKGROUND now form a pair
    the same size as the volume pair; rear board standoffs moved back
    - Design: button toggles background mode in software; the server can
    set or reset it, latest change wins
    - README updated to match
    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
    [button_caps.stl, lid.stl]
2026-10-02 Rename the project to Holler
    Update the README, design doc, component READMEs, and the enclosure
    generator header to the new name.
    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
2026-10-02 Add the in-wall endpoint model for a double-gang box
    - hardware/inwall: parametric generator, STLs (carrier, sled, cover,
    button caps, driver ring), a reference box model, and renders
    - The generator checks every part, the dummy components, and the box
    for overlap
    - Design 3.1 mechanical section and READMEs updated
    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
    [box_reference.stl, button_caps.stl, carrier.stl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]
2026-10-02 Make every status light indirect and bedroom-safe
    - Design: no LED points at the room; the glow sits behind the grille
    cloth on both endpoints, and green only shows in answer to a press
    - Tabletop: remove the front light bar; LED hole above the tweeter
    under the grille ring, with a hooded channel in the ring
    - In-wall: remove the light pipe and cover window; LED groove in the
    carrier at the top of the speaker opening
    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
    [base.stl, carrier.stl, cover.stl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]
2026-10-02 In-wall endpoint: PoE over Ethernet is the only power option
    - Design: in-wall power is PoE only, wired Ethernet only; local supply
    and Wi-Fi options removed for this endpoint
    - Sled: tray for a Waveshare ESP32-S3-ETH PoE board with its RJ45 jack
    at the edge, cable tie-down slots, amp tray moved
    - Fit checks now include the board, jack, PoE module, and plug
    - READMEs updated
    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
    [sled.stl]
2026-10-02 Documentation pass: bring every README and the design doc up to date
    - README: status covers both speakers; new in-wall section; link to
    the tabletop folder
    - hardware/tabletop: add a README with parts, hardware, and print notes
    - firmware README: two build targets, background mode, button and
    status glow behavior
    - Design: fix stale tabletop print notes, hardware list, assembly
    step, software summary, and future extensions
    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
